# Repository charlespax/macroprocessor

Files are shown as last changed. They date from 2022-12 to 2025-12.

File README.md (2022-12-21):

# macroprocessor
A project to create a microprocessor optimized for human visual verification

# Introduction
A user should be able to trust the output of a computational device without having to trust
the computatoinal device itself.

# Application
## Cryptographic security
Bitcoin

# Design
The design is not optimized for price, area, power, efficiency, yield, or other 
traditional parameter. The design is optimized for human readability and understanding.

## Requirements
- MUST be visible to a human with minimal optical magnification
- An integrated circuit design layout SHOULD aid understanding
- IC layout SHOULD correspond to the layout as seen in a digitial simulation
- Microprocessor design architecture SHOULD be optimized for understanding
- The registers or other circuitry MAY emit light
- MAY have features to aid cryptography
- MAY have serial output for debugging or other purposes

## Design notes
The overall chip layout and data flow SHOULD run from left to right.

Logical elements SHOULD have inputs on the left and outputs on the right

The metal layer or other features MUST NOT obscure any features such that 
the circuit can not be verified visually.

Chip packaging MUST NOT obscure the electrical path from the IC to the
package pins.

The design MAY use multiple IC components if each component meets the
requirements of this document.

The design MAY include wire-bonded components

# Notes
- RISC-V RV32I or RV32E are candidates
- Research making a Forth-native processor
- Can the macroprocessor be made using the same process as LEDs?
- Can a wafer be put through a secondary LED process to create registers that
  emit light?
- What is the current state of light-emitting transistors (LETs)?
- Can I use diode logic and use LEDs?
- I believe the normal silicon process cannot be used to create features that
  emit light because the band gap of silicon is too greaet. True?
- RISC-V would be a great choice if it can be visually verified. This has the 
  advantage that many more eyes would be on the chip. However, I think it is
  more important to make choices that result in more users in verifying their
  own devices.
- Check out https://zeroToASICCourse.com - this is a course for designing and ordering
  your own chip designs.
- Check out https://developers.google.com/silicon - Google's wafer batching
  program for open source designs. Cool, but I am happy to pay if reasonable.
- MAY take an external diode-based ROM
- Is there anything about this processor that would make it bad at cryptographic
  functions? Minimal circuitry could be included to address issues.
- Can x-ray crystalography be used to verify the surface of an IC?
- https://www.skywatertechnology.com is a US-based silicon fab. 
- What happens to the equipment from old semiconductor fabrication technologies?
- Fab technologies: https://en.wikipedia.org/wiki/Semiconductor\_device\_fabrication
- Are there fabs that use old technologies for new chips?
- Wire bonding can be used in places where the metal layer would obscure layers below
- wire bonding can be used as jumpers that can be cut to permanently disable a ffeature
- Rather than wire bonding, the connections can be routed to the outside of the package,
  so they can be explicetly enabled
- Maybe multi gate transistors can be used on such large features if one large gate is
  not appropriate
- Make the binary instruction decoding physicallyl easy to see on the die. Put them
  in the same order you would find them in a specification table
- Is silicon transparent to any frequency of light? If so, maybe  this can be
  used for verification and would be a design consideration.

# Conventions
The keywords below are to be interpreted as described in BCP14 [RFC2119] [RFC8174].
- MUST
- MUST NOT
- REQUIRED
- SHOULD
- SHOULD NOT
- RECOMMENDED
- NOT RECOMMENDED
- MAY
- OPTIONAL

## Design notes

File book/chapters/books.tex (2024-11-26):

\setchapterimage{seaside}
\setchapterpreamble[u]{\margintoc}
\chapter{Books}
\labch{Books}

This chapter is just a bunch of books.

Starting FORTH by Leo Brodie \cite{Brodie1981}

Thinking Forth by Leo Brodie \cite{Brodie1984}

Stack Computers: The New Wave by Philip J. Koopman \cite{Koopman1989}

Threaded Interpretive Languages by R. G. Loeliger \cite{Loeliger1981}

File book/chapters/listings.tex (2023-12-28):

\setchapterimage{seaside}
\setchapterpreamble[u]{\margintoc}
\chapter{Code Listings}
\labch{codelistingsn}

\fixed{\textbf{!}}\hspace{2mm} ( $n$ \ $addr$ --- ) Store $n$ at $addr$.
\begin{lstlisting}
    : !  ( n addr -- )
        TOS> ,>MAR
        TOS> ,>PM
\end{lstlisting}

\fixed{\textbf{:}}\hspace{2mm} ( --- ) Colon definition. Create a new word.
Usage:  : <word> <...> ;
\begin{lstlisting}
    : :  ( -- )
\end{lstlisting}

\fixed{\textbf{;}}\hspace{2mm} ( --- ) Terminate a colon definition. Resume interpretation.
Usage: : <word> <...> ;
\begin{lstlisting}
    : ;  ( -- )
\end{lstlisting}

\fixed{\textbf{>r}}\hspace{2mm} ( n --- ) Move $n$ from data stack to return stack.
\begin{lstlisting}
    : >r  ( n -- )
        TOS> ,>RS
\end{lstlisting}

\fixed{\textbf{@}}\hspace{2mm} ( $addr$ --- $n$ ) Put on TOS the value $n$ stored at address $addr$.
\begin{lstlisting}
    : @  ( addr -- n )
        TOS> ,>MAR
        PM> ,>TOS
\end{lstlisting}

\fixed{\textbf{(create)}} 
\begin{lstlisting}
    : (create)  ( -- )
\end{lstlisting}

\fixed{\textbf{,}}\hspace{2mm} Allot one cell of dictionary space. Store n at that cell's address.
\begin{lstlisting}
    : ,  (n -- ) 
                 
\end{lstlisting}

\fixed{\textbf{blk}}\hspace{2mm} User variable. Located at address \fixed{addr} is the number
of the block being interpreted.
\begin{lstlisting}
    : blk  ( -- addr ) ( User variable. Located at address addr )
                       ( is the number )
                       ( of the block being interpreted )
\end{lstlisting}

\fixed{\textbf{here}}
\begin{lstlisting}
    : here  ( -- addr ) ( Put on TOS the address of the next free )
                        ( cell in the dictionary )
\end{lstlisting}

\fixed{\textbf{interpret}}\hspace{2mm} ( --- ) Interpret the input string.
\begin{lstlisting}
    : interpret  ( -- )
\end{lstlisting}

\fixed{\textbf{next}}\hspace{2mm} ( --- ) Compile the machine instructions which simulate the 
Forth machine's \fixed{next} function. Must be used at the exit point of each code or ;code
definition.
\begin{lstlisting}
    : next  ( -- )
\end{lstlisting}

\fixed{\textbf{r>}}\hspace{2mm} ( --- $n$ ) Move $n$ from return stack to data stack.
\begin{lstlisting}
    : r>  ( ( -- n )
        RS> ,>TOS
\end{lstlisting}

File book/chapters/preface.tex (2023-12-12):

\chapter*{Preface}
\addcontentsline{toc}{chapter}{Preface} % Add the preface to the table of contents as a chapter

This is the preface page. This book is broken into two parts:

\begin{itemize}
	\item Hardware
	\item Software
\end{itemize}

The main goal of this project is to create a system that a user can visually verify down
to the transistor level. The physical layout of the circuit should correspond to the
schematic drawing layout where possible.

\begin{flushright}
	\textit{Charles Edward Pax}
\end{flushright}

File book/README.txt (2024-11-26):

Kaobook
-------------------
This book uses the kaobook templates found at
https://github.com/fmarotta/kaobook

Kaobook files:
    kaobook.cls
    kaohandt.cls
    kao.sty
    kaobiblio.sty
    kaorefs.sty
    kaotheorems.sty

My main document file is main.tex

To compile the main kaobook sample document, execute compileall.sh.

To remove generated files, execute clean.sh.

Commands to get setup the compile environment in Linux Mint 21.2:
sudo apt-get install texlive texlive-latex-extra texlive-fonts-extra texlive-science texlive-bibtex-extra biber xindy

You sould probably accomplish the same thing by installing texlive-full, but
I have not tried this.
sudo apt-get install texlive-full

Troubleshooting
-------------------

Error: `biblatex.sty' not found
Solution:  sudo apt-get install texlive-bibtex-extra biber

Glossary not compiling
sudo apt-get install xindy

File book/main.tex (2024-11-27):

%----------------------------------------------------------------------------------------
%	PACKAGES AND OTHER DOCUMENT CONFIGURATIONS
%----------------------------------------------------------------------------------------

\documentclass[
    letterpaper, % Page size: letterpaper (8.5x11 in, a4paper, executivepaper (7x10 in)
	fontsize=10pt, % Base font size
	twoside=true, % Use different layouts for even and odd pages 
                      % (in particular, if twoside=true, the margin column will be always on the outside)
	%open=any, % If twoside=true, uncomment this to force new chapters to start on any page, not only on right (odd) pages
	%chapterentrydots=true, % Uncomment to output dots from the chapter name to the page number in the table of contents
	numbers=noenddot, % Comment to output dots after chapter numbers; the most common values for this 
                          % option are: enddot, noenddot and auto (see the KOMAScript documentation for an in-depth explanation)
]{kaobook}

% Choose the language
\ifxetexorluatex
	\usepackage{polyglossia}
	\setmainlanguage{english}
\else
	\usepackage[english]{babel} % Load characters and hyphenation
\fi
\usepackage[english=british]{csquotes}	% English quotes

% Load packages for testing
\usepackage{blindtext} % Similar to lorem ipsum
%\usepackage{showframe} % Uncomment to show boxes around the text area, margin, header and footer
%\usepackage{showlabels} % Uncomment to output the content of \label commands to the document where they are used

% Load the bibliography package
\usepackage{kaobiblio}
\addbibresource{main.bib} % Bibliography file

% Load mathematical packages for theorems and related environments
\usepackage[framed=true]{kaotheorems}

% Load the package for hyperreferences
\usepackage{kaorefs}

\graphicspath{{examples/documentation/images/}{images/}} % Paths in which to look for images

\makeindex[columns=3, title=Alphabetical Index, intoc] % Make LaTeX produce the files required to compile the index

\makeglossaries % Make LaTeX produce the files required to compile the glossary
\input{glossary.tex} % Include the glossary definitions

\makenomenclature % Make LaTeX produce the files required to compile the nomenclature

% Reset sidenote counter at chapters
%\counterwithin*{sidenote}{chapter}

% Load the package for byte field graphic generation
% https://ctan.org/pkg/bytefield
\usepackage{bytefield}

% Load the package for timing diagrams
% https://ctan.org/pkg/tikz-timing
\usepackage{tikz-timing}[2009/05/15]

% Load package for drawing diagrams
\usetikzlibrary{positioning, matrix, arrows.meta,calc}

% New Command for fixed width text
\newcommand{\fixed}[1]{\texttt{#1}}

%----------------------------------------------------------------------------------------
% Packages to consider
%----------------------------------------------------------------------------------------
% CircuiTikZ
% https://ctan.org/pkg/circuitikz
% The package provides a set of macros for naturally typesetting electrical and (somewhat 
% less naturally, perhaps) electronic networks. 

%----------------------------------------------------------------------------------------
% Notes
%----------------------------------------------------------------------------------------
% - This Reddit thread has many good links for understanding the inner workings of
%   the Forth system.
%   https://www.reddit.com/r/Forth/comments/8j6rsw/i_dont_understand_whats_happening_under_the_hood/
%
% - Check out preForth and seedForth. There's a video on youtube
%
% - Structure the book based on abstraction layers
%   * Instruction Set Architecture
%   * Machine Architecture
%   * Machine code
%   * Hardware Architecture
%   * Hardware virtualization
%   * ASIC implementation

%---------------------------------------------------------------------------------------

\begin{document}

%----------------------------------------------------------------------------------------
%	BOOK INFORMATION
%----------------------------------------------------------------------------------------

%\titlehead{The \texttt{kaobook} class}
%\subject{Use this document as a template}

\title[The Forth Enlightenment]{The Forth Enlightenment}
\subtitle{Hardware for the Forth programming language}

\author[Charles Edward Pax]{Charles Edward Pax}

\date{\today}

\publishers{Self-publishing}

%----------------------------------------------------------------------------------------

\frontmatter % Denotes the start of the pre-document content, uses roman numerals

%----------------------------------------------------------------------------------------
%	OPENING PAGE
%----------------------------------------------------------------------------------------

%\makeatletter
%\extratitle{
%	% In the title page, the title is vspaced by 9.5\baselineskip
%	\vspace*{9\baselineskip}
%	\vspace*{\parskip}
%	\begin{center}
%		% In the title page, \huge is set after the komafont for title
%		\usekomafont{title}\huge\@title
%	\end{center}
%}
%\makeatother

%----------------------------------------------------------------------------------------
%	COPYRIGHT PAGE
%----------------------------------------------------------------------------------------

%\makeatletter
%\uppertitleback{\@titlehead} % Header
%
%\lowertitleback{
%	\textbf{Disclaimer}\\
%	Warranty disclaimer here
%	
%	\medskip
%	
%	\textbf{Copyright}\\
%	Copyright \textcopyright 2023 Charles Edward Pax. All rights reserved, for now.
%	
%	\medskip
%	
%	\textbf{Colophon} \\
%	This document was typeset with the help of \href{https://sourceforge.net/projects/koma-script/}{\KOMAScript} 
%       and \href{https://www.latex-project.org/}{\LaTeX} using the \href{https://github.com/fmarotta/kaobook/}{kaobook} class.
%	
%	The source code of this book template is available at:\\\url{https://github.com/fmarotta/kaobook}
%	
%	\medskip
%	
%	\textbf{Publisher} \\
%	First printed in December 2023 by \@publishers
%}
%\makeatother

%----------------------------------------------------------------------------------------
%	DEDICATION
%----------------------------------------------------------------------------------------

%\dedication{
%	It would be nice to have a dedication to a person or group of people.\\
%	\flushright -- Charles Edward Pax
%}

%----------------------------------------------------------------------------------------
%	OUTPUT TITLE PAGE AND PREVIOUS
%----------------------------------------------------------------------------------------

% Note that \maketitle outputs the pages before here

\maketitle

%----------------------------------------------------------------------------------------
%	PREFACE
%----------------------------------------------------------------------------------------

%\input{chapters/preface.tex}
%\index{preface}

%----------------------------------------------------------------------------------------
%	TABLE OF CONTENTS & LIST OF FIGURES/TABLES
%----------------------------------------------------------------------------------------

\begingroup % Local scope for the following commands

% Define the style for the TOC, LOF, and LOT
%\setstretch{1} % Uncomment to modify line spacing in the ToC
%\hypersetup{linkcolor=blue} % Uncomment to set the colour of links in the ToC
\setlength{\textheight}{230\hscale} % Manually adjust the height of the ToC pages

% Turn on compatibility mode for the etoc package
\etocstandarddisplaystyle % "toc display" as if etoc was not loaded
\etocstandardlines % "toc lines" as if etoc was not loaded

\tableofcontents % Output the table of contents

%\listoffigures % Output the list of figures

% Comment both of the following lines to have the LOF and the LOT on different pages
\let\cleardoublepage\bigskip
\let\clearpage\bigskip

%\listoftables % Output the list of tables

\endgroup

%%%==============================================================================%%%
%%%==============================================================================%%%
%%%                                                                              %%%
%%%    ███╗   ███╗ █████╗ ██╗███╗   ██╗    ██████╗  ██████╗ ██████╗ ██╗   ██╗    %%%
%%%    ████╗ ████║██╔══██╗██║████╗  ██║    ██╔══██╗██╔═══██╗██╔══██╗╚██╗ ██╔╝    %%%
%%%    ██╔████╔██║███████║██║██╔██╗ ██║    ██████╔╝██║   ██║██║  ██║ ╚████╔╝     %%%
%%%    ██║╚██╔╝██║██╔══██║██║██║╚██╗██║    ██╔══██╗██║   ██║██║  ██║  ╚██╔╝      %%%
%%%    ██║ ╚═╝ ██║██║  ██║██║██║ ╚████║    ██████╔╝╚██████╔╝██████╔╝   ██║       %%%
%%%    ╚═╝     ╚═╝╚═╝  ╚═╝╚═╝╚═╝  ╚═══╝    ╚═════╝  ╚═════╝ ╚═════╝    ╚═╝       %%%
%%%                                                                              %%%
%%%  https://patorjk.com/software/taag/#p=display&f=ANSI%20Shadow&t=MAIN%20BODY  %%%
%%%==============================================================================%%%
%%%==============================================================================%%%

\mainmatter % Denotes the start of the main document content, resets page numbering and uses arabic numbers
\setchapterstyle{kao} % Choose the default chapter heading style

\input{chapters/introduction.tex}
\input{chapters/hardware.tex}
\input{chapters/instructionsetarchitecture.tex}
\input{chapters/forth.tex}
\input{chapters/system.tex}
\input{chapters/chaptertemplate.tex}
\input{chapters/listings.tex}

\appendix % From here onwards, chapters are numbered with letters, as is the appendix convention

\input{chapters/appendix.tex}

%----------------------------------------------------------------------------------------

\backmatter % Denotes the end of the main document content
\setchapterstyle{plain} % Output plain chapters from this point onwards

%----------------------------------------------------------------------------------------
%	BIBLIOGRAPHY
%----------------------------------------------------------------------------------------

% The bibliography needs to be compiled with biber using your LaTeX editor, or on the command line with 'biber main' from the template directory

\defbibnote{bibnote}{Works are listed in order of first citation.\par\bigskip} % Prepend this text to the bibliography
\printbibliography[heading=bibintoc, title=Bibliography, prenote=bibnote] % Add the bibliography heading to the ToC, set the title of the bibliography and output the bibliography note

Title:  Implementing the Forth Inner Interpreter in High Level Forth
Date:  2016-09
URL:  http://www.euroforth.org/ef16/papers/hoffmann.pdf
Abstract:  This document defines a Forth threaded code (inner) interpreter written entirely in
    high level standard Forth. For this it defines a specific threaded code structure of colon
    definitions, a compiler from high level Forth to this threaded code and a corresponding
    inner interpreter to execute it. This inner interpreter can run in a stepwise way and so gives
    the surrounding environment control of its execution behavior. A real time environment
    thus might slice the execution of threaded code in small pieces and provide an interactive
    command shell while still meeting its real time requirements.
References:
    [1] A synchronous FORTH framework for hard real-time control, U. Hoffmann and A. Read, euroForth 2016
    [2] Threaded Interpretive Languages: Their Design and Implementation, R. G. Loeliger, McGraw Hill, 1981
Notes:
   - This paper describes a Forth inner interpreter that runs inside a Forth system. This allows
   the Forth system to control the execution of the 'virtual' interpreter. This is relevant
   to Real-Time Operating Systems (RTOS).
   - This paper is not relevant to the MacroProcessor Forth system

Title:  Fig-Forth internals
Date: 2021-09
URL:  https://www.jimbrooks.org/archive/programming/forth/FIG-FORTH\_internals.php
Abstract:  My notes from studying and modifying 8086 assembly code of FIG-FORTH. Describes
    how FIG-FORTH interpreter executes internally, how interpreting and compiling are virtually 
    the same operation, ingenious solutions used to assemble FORTH interpreter. Also describes 
    modifying FIG-FORTH to have direct-threaded code (DTC). 
Notes:
    - These notes are likely to be useful in understanding more low-level information.
    - This is not a walkthrough of the Forth system
    -"When FORTH starts, it begins executing machine-code of physical CPU. FORTH registers 
    IP SP RP of FORTH virtual processor are initialized. System words COLD WARM ABORT are 
    executed which completes initialization. ABORT executes QUIT"
    - "During execution of COLD which starts a FIG-FORTH system, QUIT creates command 
    prompt. QUIT contains words QUERY INTERPRET. QUERY accepts commands, INTERPRET 
    interprets or compiles them. QUIT emits OK message after INTERPRET returns."

%----------------------------------------------------------------------------------------
%	NOMENCLATURE
%----------------------------------------------------------------------------------------

% The nomenclature needs to be compiled on the command line with 'makeindex main.nlo -s nomencl.ist -o main.nls' from the template directory

\nomenclature{$c$}{Speed of light in a vacuum inertial frame}
\nomenclature{$h$}{Planck constant}
\nomenclature{CFA}{See Code Field Address}
\nomenclature{LFA}{See Link Field Address}
\nomenclature{NFA}{See Name Field Address}
\nomenclature{PFA}{See Parameter Field Address}

\renewcommand{\nomname}{Notation} % Rename the default 'Nomenclature'
\renewcommand{\nompreamble}{The next list describes several symbols that will be later used within the body of the document.} % Prepend this text to the nomenclature

\printnomenclature % Output the nomenclature

%----------------------------------------------------------------------------------------
%	GLOSSARY
%----------------------------------------------------------------------------------------

% The glossary needs to be compiled on the command line with 'makeglossaries main' from the template directory

\setglossarystyle{altlist} % Set the style of the glossary (see https://en.wikibooks.org/wiki/LaTeX/Glossary for a reference)
\glsaddall % print all terms in the glossary, not only referenced words
\printglossary[title=Glossary, toctitle=Glossary,nonumberlist] % Output the glossary, 'title' is the chapter heading for the glossary, toctitle is the table of contents heading

Dictionary
===================

;  "Semi-colon"
Terminates a definition created by : .

1. Exits colon definition mode
2. Addes the definition to the dictionary
3. Enters interpretation mode

    : ; ( -- )
        ( definition goes here ) ;

NEXT  "Next"
Terminates a code-word and jumps to the next instruction.

1. Fetch the Code Field Address (CFA),
   which is stored in a cell,
   which is pointed to by the Forth Instruction Pointer (IP)
2. Increment the Forth IP,
   which will then point to the proceeding cell,
   which contains the next Forth instruction
3. Jump to the fetched CFA

    : NEXT ( -- )
        RS> ,>PC ,R--

Notes:
   - What is a cell? I think this is address of the code field of the
   proceeding Forth word. The IP always points to the next CFA to be
   executed.
   - Does the cell located at the CFA hold a machine instruction or
   is there a Forth dictionary word there? I think the contents of the
   cell pointed to by the CFA in the IP is always a machine instruction.
   I think the word INTERPRET handles the task of looking through the
   dictionary and determining the CFA of that word. The CFA should be
   the first cell of a word's code field, which can be one or more cells.

%----------------------------------------------------------------------------------------
%	INDEX
%----------------------------------------------------------------------------------------

% The index needs to be compiled on the command line with 'makeindex main' from the template directory

\printindex % Output the index

%----------------------------------------------------------------------------------------
%	BACK COVER
%----------------------------------------------------------------------------------------

% If you have a PDF/image file that you want to use as a back cover, uncomment the following lines

%\clearpage
%\thispagestyle{empty}
%\null%
%\clearpage
%\includepdf{cover-back.pdf}

%----------------------------------------------------------------------------------------

\end{document}

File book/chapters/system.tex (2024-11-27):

\setchapterimage{seaside}
\setchapterpreamble[u]{\margintoc}
\chapter{The Forth System}
\labch{chaptertemplate}

%
% Key concepts and abilities
%==============================================================================
\begin{kaobox}[frametitle=In This Chapter]
you will learn
\begin{itemize}
	\item what is the first topic
	\item how to identify the second topic
        \item best practices for the third topic
\end{itemize}

you will be able to
\begin{itemize}
        \item perform the steps required to accomplish task one
        \item create a program that performs task two
\end{itemize}
\end{kaobox}

This introduction gives the reader any context necessary to understand the 
proceeding sections in this chapter.

The contents of the `In This Chapter' box should concrete. This should coorespond to
a `Chapter Review' section at the end of the chapter.

Illuminate any common obstacles for the reader. A few words of encouragement are also welcomed.

%
% Section: Things Forth Does
%==============================================================================
\section{Things Forth Does}
\subsection{System Operations}
Note: the text interpreter handles input from terminal and files. It also 
handles compilation

\subsubsection{Initialize system}
Copy values into the correct location in memory. Set register values. Example: 
Read from memory the designated address for the stack pointer and load that 
into a particular register.

\subsubsection{Interpret input stream}
The outer interpreter (AKA text interpreter). The input stream could be a 
keyboard buffer, serial buffer, or other source.

\subsubsection{Execution}
'Innter interpreter.' 'Address interpreter.' Track which word is being executed
and which to execute next. Jumping to machine code. Controls the flow of 
execution.

\subsubsection{Error detection and handling}
Usually by clearing the stack and returning control to the outer interpreter.

%
% Section: Forth System Parameters
%==============================================================================
\section{Forth System Parameters}
Data Stack Pointer (DS), Return Stack Pointer (RS), Interpreter Pointer(IP),
Word Pointer (W).

Data Stack Pointer. Holds the address of the top cell of the data stack. SP can be in memory or in a register. Register is better. This paragraph is true for systems that have the stack in RAM.

The data stack can be held in memory or in hardware stack provided by the CPU. The same is true of the return stack.

When using a hardware stack provided by the CPU, the Top of Stack (ToS) element is typically the only element that can be accessed by the data bus. Some microprocessors provide access to multiple cells. Three cells are a good number (Stack Computers?).

Return Stack Pointer (RS). Similar to the data stack. The data stack pointer and the data stack itself can beach be stored in memory. RS can be a hardware stack, but doing so does not provide the same performence gain as doind so with the data stack (source?).

During execution, a word may use the Return Stack for temkporary storage. Be careful!

Interpretative Pointer (IP). 'instruction pointer?'. Points to the code field (?) of the next word to be executed. Does thi depend on the system implementation? Can be stored in memory or a register.

Word Pointer (WP). Points to the word currently being executed. (Name field? Code field?).
% Chapter Review
%==============================================================================
\section{Chapter Review}
\begin{kaobox}[frametitle=Chapter Review]
you have learned
\begin{itemize}
	\item what is the first topic
	\item how to identify the second topic
        \item best practices for the third topic
\end{itemize}

you are able to
\begin{itemize}
        \item perform the steps required to accomplish task one
        \item create a program that performs task two
\end{itemize}
\end{kaobox}

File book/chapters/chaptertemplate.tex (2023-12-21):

\setchapterimage{seaside}
\setchapterpreamble[u]{\margintoc}
\chapter{Template Chapter}
\labch{chaptertemplate}

%
% Key concepts and abilities
%==============================================================================
\begin{kaobox}[frametitle=In This Chapter]
you will learn
\begin{itemize}
	\item what is the first topic
	\item how to identify the second topic
        \item best practices for the third topic
\end{itemize}

you will be able to
\begin{itemize}
        \item perform the steps required to accomplish task one
        \item create a program that performs task two
\end{itemize}
\end{kaobox}

This introduction gives the reader any context necessary to understand the 
proceeding sections in this chapter.

The contents of the `In This Chapter' box should concrete. This should coorespond to
a `Chapter Review' section at the end of the chapter.

Illuminate any common obstacles for the reader. A few words of encouragement are also welcomed.

%
% Section: Heaps of Examples
%==============================================================================
\section{Heaps of Examples}
This section is fairly dense with examples. You can delete everything from here until
the end of the page.\sidenote[]{After you have saved this document as a new file.}

This section serves as an easy way to demonstrate\footnote{Like this footnote} multiple 
graphical elements\todo{Add a list of elements} that can be used in this book.

Keep chapters, sections, and sub sections capitalized.

%
% Subsection: Margin Stuff
%------------------------------------------------------------------------------
\subsection{Margin Stuff}
Generally, any text that would be written between parentheses would do well as
a margin note. Keep the flow going.

\marginnote{
	\begin{kaobox}[frametitle=Remember]
		a kaobox can be used in the margins for special reminders)
	\end{kaobox}
}

%
% Subsubsection: Sections in Depth
%
\subsubsection{Sections in Depth}
Sections within a chapter can be \Command{section}, \Command{subsection}, or
\Command{subsubsection}\marginnote{Notice that \Command{subsubsection} does not cause numbering.}.

%
% Subsection: Figures and Tables}
%------------------------------------------------------------------------------
\subsection{Figures and Tables}
\begin{lstlisting}[caption={
This Forth code does NOT generate \reftab{useless}
}]
: square  ( x -- x )
( Forth code that squares a number
    dup * ;
\end{lstlisting}

This is an example of a table contained withing the main column of text.

\begin{table}[ht]
\caption[A useless table]{A useless table.}
\labtab{useless}
\begin{tabular}{ c c c c }
    \toprule
    col1          & col2  & col3  & col4\\
    \midrule
    \multirow{3}{4em}{
    Multiple row} & 
        cell2 & cell3 & cell4\\ &
        cell5 & cell6 & cell7 \\ &
        cell8 & cell9 & cell10 \\
    \multirow{3}{4em}{
    Multiple row} & 
        cell2 & cell3 & cell4 \\ &
        cell5 & cell6 & cell7 \\ &
        cell8 & cell9 & cell10 \\
    \bottomrule
\end{tabular}
\end{table}

We can also have full-width tables.

\begin{table*}[h!]
    \caption{A wide table with invented data about three people living in the UK. Note that wide figures and tables are centered and their caption also extends into the margin.}
    \begin{tabular}{p{2.0cm} p{2.0cm} p{2.0cm} p{2.0cm} p{2.0cm} p{2.0cm} p{1.5cm}}
        \toprule
        Name    & Surname   & Job       & Salary           & Age   & Height    & Country \\
        \midrule
        Alice   & Red       & Writer    & 4.000 \pounds    & 34    & 167 cm     & England \\
        Bob     & White     & Bartender & 2.000 \pounds    & 24    & 180 cm     & Scotland \\
        Drake   & Green     & Scientist & 4.000 \pounds    & 26    & 175 cm     & Wales \\
        \bottomrule
    \end{tabular}
\end{table*}

And full-width images.

\blindtext

\begin{figure*}[h!]
	
	\caption[A wide seaside]{A wide seaside, and a wide caption.
		Credits: By Bushra Feroz, CC BY-SA 4.0, \url{https://commons.wikimedia.org/w/index.php?curid=68724647}}
\end{figure*}

\begin{marginfigure}
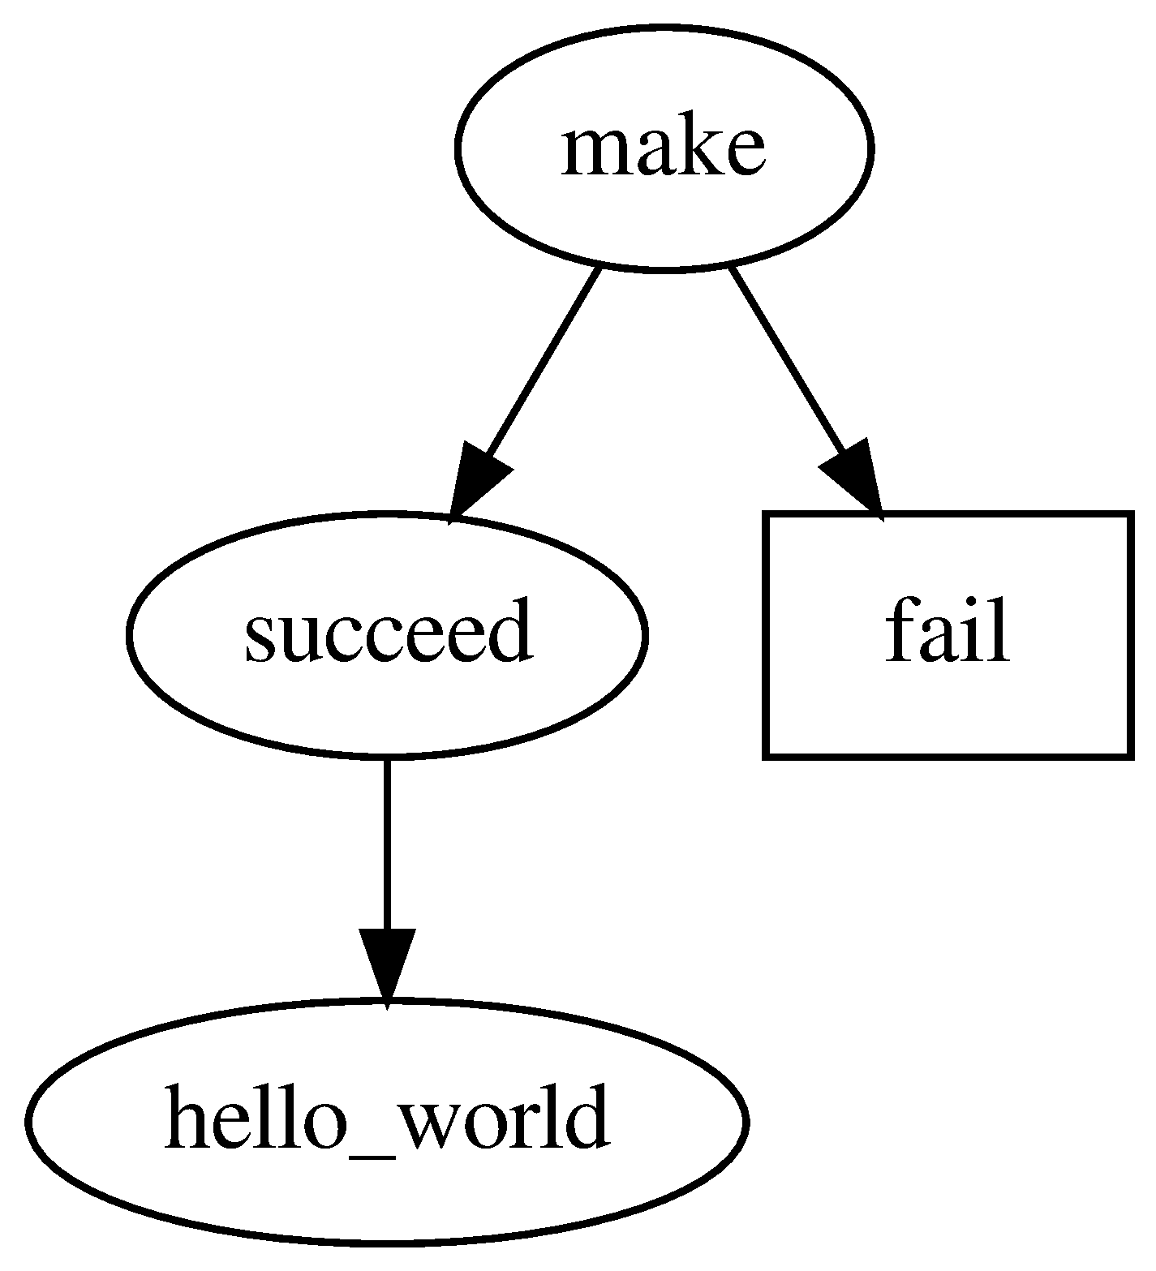
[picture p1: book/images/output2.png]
	
	\caption[A Dot diagram]{A diagram produced by the Dot program and saved as a PNG file.}
	\labfig{marginmonalisa}
\end{marginfigure}

%
% Subsection: Citations
%------------------------------------------------------------------------------
\subsection{Citations}
Cite an author in the margin\sidecite{example1999}.

\blindtext

%
% Subsection: Glossaries and Indicies
%------------------------------------------------------------------------------
\subsection{Glossaries and Indicies}

%
% Subsection: Mathematics
%------------------------------------------------------------------------------
\subsection{Mathematics}
The box below was created using the \Environment{definition} environment. Boxes are also
provided by the \Environment{theorem}, \Environment{proposition}, \Environment{lemma},
\Environment{corollary}, \Environment{example}, \Environment{remark}, and \Environment{exercise} environments.

\begin{definition}
\labdef{exdeflabel}
Let $y$ be some function of $x$ such that $y = f(x)$
\end{definition}

where $x$ and $y$ are both variables in \refdef{exdeflabel}.

\blindtext

%
% Chapter Review
%==============================================================================
\section{Chapter Review}
\begin{kaobox}[frametitle=Chapter Review]
you have learned
\begin{itemize}
	\item what is the first topic
	\item how to identify the second topic
        \item best practices for the third topic
\end{itemize}

you are able to
\begin{itemize}
        \item perform the steps required to accomplish task one
        \item create a program that performs task two
\end{itemize}
\end{kaobox}

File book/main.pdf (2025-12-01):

# The Forth Enlightenment

Hardware for the Forth programming language

## Charles Edward Pax

## December 11, 2024

## Self-publishing

# Contents

Contents | iii
1 Introduction | 1
2 Hardware | 3
3 Instruction Set Architecture (ISA) | 7
4 The Forth Programming Language | 11
5 The Forth System | 17
6 Template Chapter | 21
7 Code Listings | 25
A Template Appendix | 27
Bibliography | 29

Notation | 31
Glossary | 33
Alphabetical Index | 35

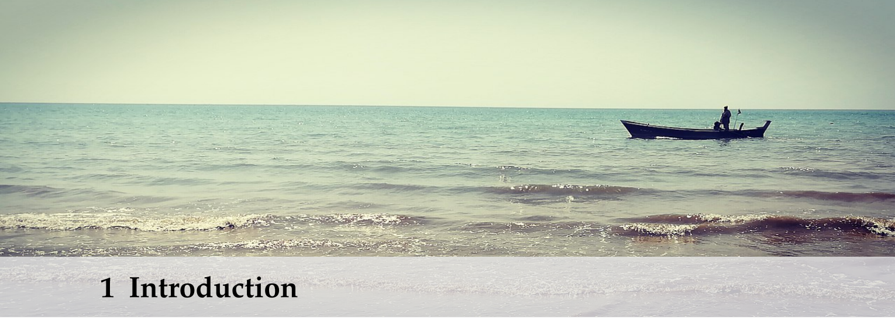
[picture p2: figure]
1 Introduction

### 1.3 Instruction set Architecture . 2

In This Chapter

you will learn

- First topic
- Second topic
- Third topic

you will be able to

- Task one
- Task two
- Task three

Hello, here is some text without a meaning. This text should show what a printed text will look like at this place. If you read this text, you will get no information. Really? Is there no information? Is there a difference between this text and some nonsense like “Huardest gefburn”? Kjift – not at all! A blind text like this gives you information about the selected font, how the letters are written and an impression of the look. This text should contain all letters of the alphabet and it should be written in of the original language. There is no need for special content, but the length of words should match the language.

## 1.1 Purpose

The purpose of this book is to address the necessity of trustless computing or verifyable computing.

- Don’t trust, verify
- trustless computing
- trusting the compiler

Design princples: simplicity is a virtue.

2 1 Introduction

### Don’t trust, verify

In this section talk about blah blah blah.

### Trustless computing

Discuss trustless computing here.

### Trusting the compilers

In this subsection there will be a discussion of trusting the compiler.

### Application: Bitcoin

These topics are relevant to Bitcoin because it relates to money. Don’t get hacket. Artificial Intelligence is coming for your money.

## 1.2 Hardware Overview

No microcode. Implement logic in hardware. Complex optimization is bad. conceptual simplicity. Simplicity is a cirtue.

visual verification view with your own eyes
simplicity keep it simple to understand
repitation repeat blocks

### Stack computers

- Why stack computers?
- Parts of a stack computer
- Types of stack computers

Do we cover the instruction cycle here? Instruction timing?

## 1.3 Instruction set Architecture

The instruction set architecture should be kept simple. Each bit encodes specific information.

The software should:

- be simple
- reuse code blocks
- not require a compiler
- be hand-writable

Threaded code. No compiler. Forth.

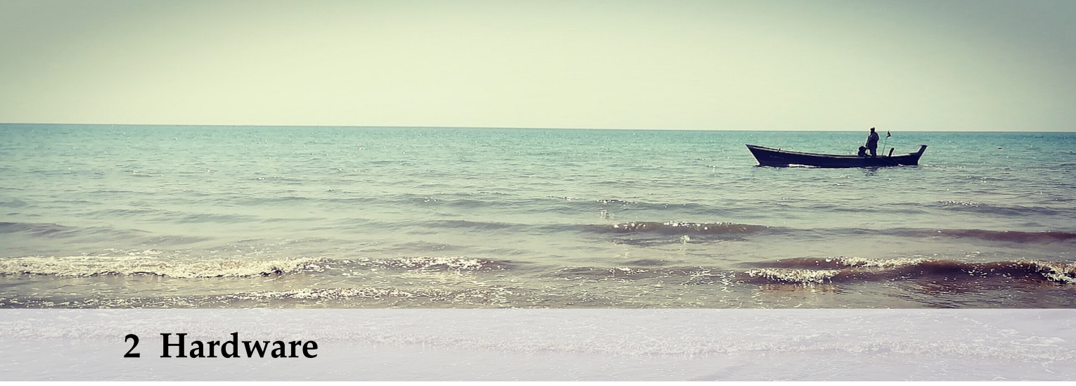
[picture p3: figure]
2 Hardware

[1]: Philip J. Koopman (1989), Stack Computers the New Wave

### 2.2 Architecture Block Diagram 3

In This Chapter

you will learn

- First topic
- Second topic
- Third topic

you will be able to

- Task one
- Task two
- Task three

Hello, here is some text without a meaning. This text should show what a printed text will look like at this place. If you read this text, you will get no information. Really? Is there no information? Is there a difference between this text and some nonsense like “Huardest gefburn”? Kjift – not at all! A blind text like this gives you information about the selected font, how the letters are written and an impression of the look. This text should contain all letters of the alphabet and it should be written in of the original language. There is no need for special content, but the length of words should match the language.

## 2.1 Stack Computers

We will discuss stack computers[1].

## 2.2 Architecture Block Diagram

4 | 2 Hardware
1 | \ | +-----+ | |||====\\ | //=====\\
2 | \ | | PC | |<===>||| | || | || | ||
3 | \ | +-----+ | | | __\/_ _\/__ | ||
4 | \ | |D| \ A | \/ | B / | ||
5 | \ | +-----+ | +-----+ | |A| | \ | ALU | / | ||
6 | \ | | IO | |==| MAR |<====|T| | \______/ | ||
7 | \ | +-----+ | +-----+ | |A| | | || | | ||
8 | \ | || | | | | +------+ | ||
9 | \ | +-----+ | |B|<====| TOS | |====//
10 | \ | | PM | |<===>|U| | +------+
11 | \ | +-----+ | |S|<===>| DS1 | |
12 | \ | | | | +------+
13 | \ | +-----+ | |||<===>| DS2 | |
14 | \ | | IR | |<===>||| | +------+
15 | \ | +-----+ | ||| | +------+
16 | \ | | CL | | | ||| | | DS31 |
17 | \ | +-----+ | ||| | +------+
18 | \ | | | |||
19 | \ | ||| | +------+
20 | \ | |||<====| RS | |
21 | \ | ||| | +------+
22 | \ | ||| | +------+
23 | \ | | RS31 |
24 | \ | +------+

Figure 2.1: Simplified architecture block diagram

2.2 Architecture Block Diagram | 5
1 | |||======================\\ | //====\\
2 | ||| | || | || | ||
3 | ||| 000 ALU_NOP | || | || | ||
4 | ||| 001 ALU_ADD | || | || | ||
5 | ||| 010 ALU_SUB | __\/___ ___\/__ ||
6 | | | 011 ALU_AND | \ | A | \/ | B | / | ||
7 | | | 100 ALU_OR | \ | / | ||
8 | +-------------------+ | 001 PC> | |1| 101 ALU_XOR | \ | ALU | / | ||
9 | | | Program | | | | |6| 110 ALU_<< | ALU_OP --\________/ | ||
10 | | | Counter | |=============#=>| | 111 ALU_>> | || | ||
11 | | | |<===============|B| | || | ||
12 | SMA_x --| (1 PC++) | |-- 001 >PC | |I| 101 TOS> | +----------\/----+ | ||
13 | | | | | |T| | | | | Top Of | | | ||
14 | +-------------------+ | | |<=#=============| | Stack | |====//
15 | || | |D| | | | |
16 | || | |A| | 101 >TOS --| | (cell 0) | |
17 | +---\/----+---------+ | 010 PM> | |T| 110 DS1> | +----------------+
18 | | Memory | | Program | | | |A| | | | | Data | |
19 | | Address | Memory |=============#=>| |<=#=============| | Stack | |
20 | | | | | |<===============|B|===============>| | Cell 1 | |
21 | SMA_x --| | | | |-- 010 >PM | |U| | 110 >DS1 --| | |
22 | 0 MAR +---/\----+---------+ | |S| 111 DS2> | +----------------+
23 | 1 PC | || | | | | | | | Data | |
24 | || | | |<=#=============| | Stack | |
25 | +-------------------+ | |||===============>| | Cell 2 | |
26 | | Memory | |<===============||| | 111 >DS2 --| | |
27 | | Address Register |-- 011 >MAR | ||| | +----------------+
28 | +-------------------+ | ||| | . | .
29 | ||| | +----------------+
30 | +-------------------+ | ||| | | | DS31 | |
31 | | | Instruction | |<===============||| | +----------------+
32 | | | Register | | | |||
33 | +-------------------+ | ||| 100 RS> | +----------------+
34 | | Instruction Cycle | | ||| | | | | Return | |
35 | | | | | |||<=#=============| | Stack | |
36 | | 00 SMA_PC | | | |||===============>| | |
37 | | 01 PM> ,>IR ,PC++ | | ||| | 100 >RS --| | (cell 0) | |
38 | | 10 | | | +----------------+
39 | | 11 CL = IR[] | | | . | .
40 | | | | Bits | Instruction Format | +----------------+
41 | +-------------------+ | 15-13 xxx------------- xyz> | | | RS31 | |
42 | | | Control Logic | | 12-10 ---xxx---------- >xyz | +----------------+
43 | | | | | 9-7 | ------xxx------- ALU_OP
44 | +-------------------+ | 6 | ---------x------ Select Memory Address (SMA)
45 | 5-4 | ----------xx---- (unallocated)
46 | 3 | ------------x--- zero
47 | 2 | -------------x-- sign
48 | 1 | --------------x- carry
49 | 0 | ---------------x overflow

Figure 2.2: Complete architecture block diagram

6 2 Hardware

Table 2.1: Instruction Set Architecture (ISA)

Word | Binary OP code | OP code description
NOP | 000 000 000 0 00 0000 | No Operation
RESET | 111 111 111 1 11 1111 | Reset system
NO> | 000 | | No input source. High Z
PC> | 001 | | Program Counter out
PM> | 010 | | Program Memory out
MAR> | 011 | | Memory Address Register out
RS> | 100 | | Return stack out
TOS> | 101 | | POP Data Stack cell 0
DS1> | 110 | | POP Data Stack cell 1
DS2> | 111 | | POP Data Stack cell 2
>NO | ... 000 | | No output destination.
>PC | ... 001 | | Input to Program Counter
>PM | ... 010 | | Input to Program Memory
>MAR | ... 011 | | Input to Memory Address Register
>RS | ... 100 | | PUSH to Return stack
>TOS | ... 101 | | PUSH to Data Stack cell 0
>DS1 | ... 110 | | PUSH to Data Stack cell 1
>DS2 | ... 111 | | PUSH to Data Stack cell 2
ALU_NOP | ... ... 000 | | No ALU operation selected
ALU_ADD | ... ... 001 | | ALU addition
ALU_SUB | ... ... 010 | | ALU subtraction
ALU_AND | ... ... 011 | | ALU bitwise AND
ALU_OR | ... ... 100 | | ALU bitwise OR
ALU_XOR | ... ... 101 | | ALU bitwise XOR
ALU_« | ... ... 110 | | ALU bitshift left
ALU_» | ... ... 111 | | ALU bitchift right
SMA_MAR | | 0 .. .... | Select Memory Address from MAR
SMA_PC | | 1 .. .... | Select Memory Address from PC
| | xx .... | (unallocated)
if=0 | | 1... | Zero
if<0 | | 1.. | Sign
if_C | | 1. | Carry
if_OF | | 1 | Overflow

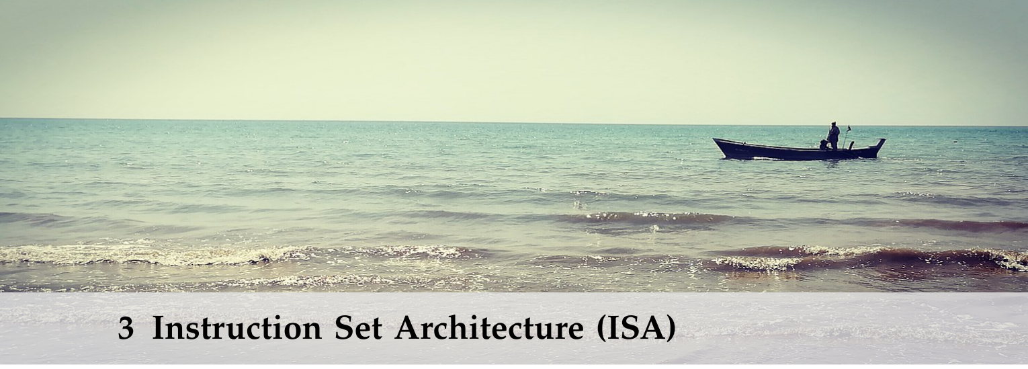
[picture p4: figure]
3 Instruction Set Architecture (ISA)

In This Chapter

you will learn

- First topic
- Second topic
- Third topic

you will be able to

- Task one
- Task two
- Task three

Hello, here is some text without a meaning. This text should show what a printed text will look like at this place. If you read this text, you will get no information. Really? Is there no information? Is there a difference between this text and some nonsense like “Huardest gefburn”? Kjift – not at all! A blind text like this gives you information about the selected font, how the letters are written and an impression of the look. This text should contain all letters of the alphabet and it should be written in of the original language. There is no need for special content, but the length of words should match the language.

## 3.1 ISA Explained

Explain what an ISA is.

## 3.2 Instruction cycle

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

8 3 Instruction Set Architecture (ISA)

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

## 3.3 Instruction Format

## 3.4 Instruction Timing

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

Figure 3.1: This is an example timing diagram that will be replaced by the real thing.

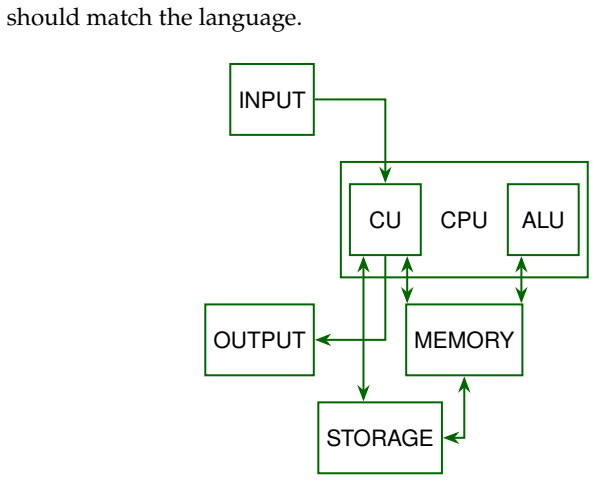
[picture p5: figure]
should match the language.; CPU; ALU; INPUT; OUTPUT; MEMORY; STORAGE

Hello, here is some text without a meaning. This text should show what a printed text will look like at this place. If you read this text, you will get no information. Really? Is there no information? Is there a difference between this text and some nonsense like “Huardest gefburn”? Kjift – not at all! A blind text like this gives you information about the selected font, how the letters are written and an impression of the look. This text should contain all letters of the alphabet and it should be written in of the original language. There is no need for special content, but the length of words should match the language. Hello, here is some text without a meaning. This text should show what a printed text will look like at this place. If you read this text, you will get no information. Really? Is there no information? Is there a difference between this text and some nonsense like “Huardest gefburn”? Kjift – not at all! A blind text like this gives you information about the selected font, how the letters are written and an impression of

3.4 Instruction Timing 9

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

RESET

Clock

Clock

Name

Signal | Text | Text | Text
Signal | Setup 00 | Setup 01 | Setup 10 | Setup 11
Signal | PC> ,>MAR | PM> ,>IR ,PC++ | PC> ,>MAR | LC=IR[]

Figure 3.2: This is an example timing diagram that will be replaced by the real thing.

### 1 _______________________________________________________________________ 2 RESET _/

3
4 | _______ | _______ | _______ | _______ | ____
5 | CLK | ____/ | \_______/ | \_______/ | \_______/ | \_______/
6 | ... | Execute 00 | | Execute 01 | | Execute 10 | | Execute 11 | |
7 | | PC> ,>MAR | | PM> ,>IR ,PC++| PC> ,>MAR | | CL=IR[] | | ...
8 | ____ | _______ | _______ | _______ | _______
9 | ~CLK | \_______/ | \_______/ | \_______/ | \_______/ | \____
10 | ... Setup 00 | | Setup 01 | | Setup 10 | | Setup 11 | | ...
11 | PC> ,>MAR | | PM> ,>IR ,PC++| PC> ,>MAR | | CL=IR[] | |

Figure 3.3: Instructions are executed. The contyrol logic is configured in between each step. Timing chart.

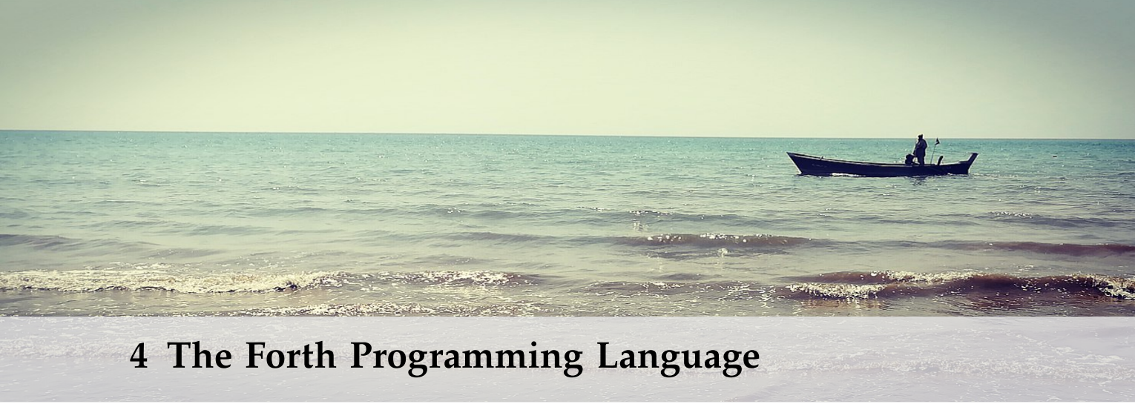
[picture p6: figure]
4 The Forth Programming Language

Add headings for these three columns: Address, Contents, Description

how are these items sorted? Alphabetical? Order of ap-pearance?

### 4.1 Dictionary Entry Format . . 11

### 4.2 The Forth Inner Interpreter . 13

### 4.5 The Forth Outter Interpreter 14

In This Chapter

you will learn

- First topic
- Second topic
- Third topic

you will be able to

- Task one
- Task two
- Task three

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

## 4.1 Dictionary Entry Format

Each word in Forth is defined by a dictionary entry immediate word.

The dictionary entry format is dependent upon the Forth implmentation, but a typical 16-bit Forth system will implement the structure described in Figure 4.1.

where
NFA is the address pointing to the first cell in the word’s name field, LFA is the address pointing to the word’s link pointer field,
CFA is the address pointing to the word’s code pointer field,
PFA is the address pointing to the first cell in the word’s parameter field,

12 4 The Forth Programming Language

Figure 4.1: Dictionary entry format.

Address | Content | Notes
15 14 | 0
Name Field Address (NFA) | p | n
NFA +1 | | name1

NFA +n | namen

name field

Link Field Address (LFA) | link pointer | link field
Code Field Addresss (CFA) | code pointer | code field
Parameter Field Address (PFA) | parameter1

PFA +c − 1 | parameterc

parameter field

This text uses the term parameter field. Other resources may use the term data field or other term.

p is the precedence bit (0,1),
n is the number of characters in the word’s name (e.g. DUPn = 3),

namen is the n

t ℎ character in the name, c is the number of cells in the parameter field, and

parameterc

is the c

t ℎ cell in the parameter field.

Each dictionary entry has a link pointer field, which holds an memory address pointing to the preceeding dictionary entry. By design, when the system searches for a word it starts at the end of the dictionary and works its way to the beginning by following these pointers. We call these addresses link pointers because they link the words together and to distinguish them from pointers with other purposes.

Each dictionary entry in the dictionary will share the same format for the name field, link field, and code field. The parameter field format depends on the word type. Constants, variables, colon-defined words, and any other type of defining word can have its own uniquie parameter field format.

The link pointer of a dictionary entry points to the name field of the previous word. The value of a link pointer is equal to the NFA of the pervious dictionary entry. The link pointer is an address pointing to the first cell of the previous dictionary entry’s name field. The LFA of a dictionary entry contains the NFA of the previous dictionary entry.i

Code pointer contains an address. This address is the "address of the instruction first executed when this type of word is executed." Starting Forth p. 222

Variable words. The code pushes the variable address onto the stack.

Constant words. The code pushes the contents of the constant onto the stack.

Colon defined words. The code executes the rest of the words in the colon definition.

In all the cases the code pointed to is called "tun-time code."

4.2 The Forth Inner Interpreter 13

The code address field is also known as the code pointer field. The data field is also known as the parameter field.

[2]: Brodie (1981), Starting FORTH

1: Use sidenotes if necessary

[3]: Loeliger (1981), Threaded Interpretive Languages

All words of a given type have the same code pointer.

code address is the address of the machine instruction the interpreter will load for execution, and
data is any data that is required for execution. todo[noline]Decide if the name field characters are 16-bit or 8-bit in the final implementation.

Precedence bit. 0 - address of the word gets compiled normally. 1 - The word is executed during compilation.

Are the characters in the name field limited to ASCII? Is there any technical reason they could not be any arbitrary 16-bit value? Maybe null would be a problem.

Leo Brodie’s Starting Forth[2] is good reading for this.

## 4.2 The Forth Inner Interpreter

This section gives a general explaination¹ of the chapter topic[3].

The word : causes the innter interpreter to enter compile mode. The name of the word is next, followed by the definition. The word ; causes the inner interpreter to exit compilation and reenter interpretation mode.

Example:

Listing 4.1: Definition of dup in Forth. 1 : square ( x -- x )

### 2 dup

3 *
4 :

This, of course, can be more conveniently written on a single line

: square ( x -- x )
dup * ;

## 4.3 Return Stack

The top of the return stack holds the return address. When a function call is made, the return address must be stored. If the call command is executed at address x, the return address x+1 is pushed to the top of the return stack.

## 4.4 Data Stack

The data styack is where temporary data is stored.

If a system has only one hardware stack, it shoulld be used for the data stack. Data manipulations are more common than function calls and the hardware stack is faster than memory access. The call stack will need to be stored in memory.

14 4 The Forth Programming Language

Margin notes can be used to explain de-tail or add reminders that would other-wise break the flow of the document. I think sidenotes are numbered while margin notes are not.

see BYO Assembler, Moving
Forth

For "colon words" (words compiled with the : word), the data field is a series of cells, each cell containing an address pointing to a word in the Forth dictionary.

The address interpreter (inner interpreter) copies the address stored in the address field into the interpreter pointer then executes the code at that address.

The interpreter does not keep track of or know about the type of word it is working with. The code linked to by the CFA is responsible for behaving appropriately.

## 4.5 The Forth Outter Interpreter

This an intermediate section. There will be several. each such section will cover a discrete topic within this chapter.

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

## 4.6 Forth Primitives

## 4.7 Metacompiler

## 4.8 Notes

Check out the YouTube channel learnmeabitcoin. The creator has a great video explaining SHA256 and another video explaining the Bitcoin Script stack machine.

Table 4.1: Example interpretation of a Forth word. This table would be paired with a code listing for the word. A column can be added for the return stack or other information. Exercises can be made in the style of fill-in-the-missing-item.

: times14 ( n1 — n2 ), n2 = 14 ∗ n1
Step | Data Stack | Interpret | Description
1 | n1 | 2 | 2 → TOS
2 | n1 2 | 3 | 3 → TOS
3 | n1 2 3 | 4 | 4 → TOS
4 | n1 2 3 4 | + | (x1 x2 — x3), x3 = x1 + x2
5 | n1 2 7 | * | (x1 x2 — x3), x3 = x1 ∗ x2
6 | n1 14 | * | (x1 x2 — x3), x3 = x1 ∗ x2
7 | n2 | ; | Return to interpreter

4.8 Notes | 15
1 | : literal | ( n -- | )
2 (Usage: : <name> ... [ n ] literal ... ; )
3 (Description: Compiles LIT and TOS number (n). When <name> is executed, n is placed on TOS.)

### 4 state @ if compile lit , then ; immediate

5
6 | :lit | ( | -- n | )

### 7 PM> ,>TOS ,PM-PC

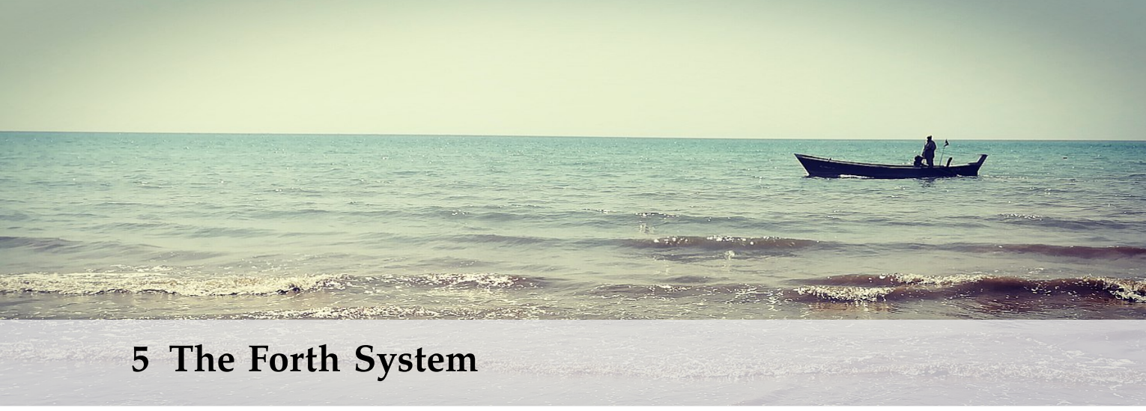
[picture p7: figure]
5 The Forth System

### 5.2 Forth System Parameters . 18

In This Chapter

you will learn

- what is the first topic
- how to identify the second topic
- best practices for the third topic

you will be able to

- perform the steps required to accomplish task one
- create a program that performs task two

This introduction gives the reader any context necessary to understand the proceeding sections in this chapter.

The contents of the ‘In This Chapter’ box should concrete. This should coorespond to a ‘Chapter Review’ section at the end of the chapter.

Illuminate any common obstacles for the reader. A few words of encour-agement are also welcomed.

## 5.1 Things Forth Does

### 5.1.1 System Operations

Note: the text interpreter handles input from terminal and files. It also handles compilation

Initialize system

Copy values into the correct location in memory. Set register values. Example: Read from memory the designated address for the stack pointer and load that into a particular register.

18 5 The Forth System

Interpret input stream

The outer interpreter (AKA text interpreter). The input stream could be a keyboard buffer, serial buffer, or other source.

Execution

’Innter interpreter.’ ’Address interpreter.’ Track which word is being executed and which to execute next. Jumping to machine code. Controls the flow of execution.

Error detection and handling

Usually by clearing the stack and returning control to the outer interpreter.

## 5.2 Forth System Parameters

Data Stack Pointer (DS), Return Stack Pointer (RS), Interpreter Pointer(IP), Word Pointer (W).

Data Stack Pointer. Holds the address of the top cell of the data stack. SP can be in memory or in a register. Register is better. This paragraph is true for systems that have the stack in RAM.

The data stack can be held in memory or in hardware stack provided by the CPU. The same is true of the return stack.

When using a hardware stack provided by the CPU, the Top of Stack (ToS) element is typically the only element that can be accessed by the data bus. Some microprocessors provide access to multiple cells. Three cells are a good number (Stack Computers?).

Return Stack Pointer (RS). Similar to the data stack. The data stack pointer and the data stack itself can beach be stored in memory. RS can be a hardware stack, but doing so does not provide the same performence gain as doind so with the data stack (source?).

During execution, a word may use the Return Stack for temkporary storage. Be careful!

Interpretative Pointer (IP). ’instruction pointer?’. Points to the code field (?) of the next word to be executed. Does thi depend on the system implementation? Can be stored in memory or a register.

Word Pointer (WP). Points to the word currently being executed. (Name field? Code field?).

5.3 Chapter Review 19

## 5.3 Chapter Review

Chapter Review

you have learned

- what is the first topic
- how to identify the second topic
- best practices for the third topic

you are able to

- perform the steps required to accomplish task one
- create a program that performs task two

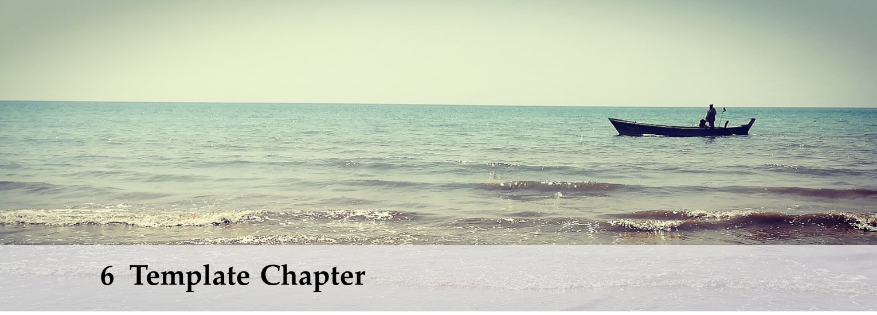
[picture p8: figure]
6 Template Chapter

1: After you have saved this document as a new file.

Add a list of elements

Remember
a kaobox can be used in the margins for special reminders)

### 6.1.4 Glossaries and Indicies . . 23

In This Chapter

you will learn

- what is the first topic
- how to identify the second topic
- best practices for the third topic

you will be able to

- perform the steps required to accomplish task one
- create a program that performs task two

This introduction gives the reader any context necessary to understand the proceeding sections in this chapter.

The contents of the ‘In This Chapter’ box should concrete. This should coorespond to a ‘Chapter Review’ section at the end of the chapter.

Illuminate any common obstacles for the reader. A few words of encour-agement are also welcomed.

## 6.1 Heaps of Examples

This section is fairly dense with examples. You can delete everything from here until the end of the page.¹

This section serves as an easy way to demonstrate‗ multiple graphical elements that can be used in this book.

Keep chapters, sections, and sub sections capitalized.

### 6.1.1 Margin Stuff

Generally, any text that would be written between parentheses would do well as a margin note. Keep the flow going.

‗ Like this footnote

22 6 Template Chapter

Notice that \subsubsection does not cause numbering.

Sections in Depth

Sections within a chapter can be \section, \subsection, or \subsubsection.

### 6.1.2 Figures and Tables

Listing 6.1: This Forth code does NOT
generate Table 6.1 | 1 | : square | ( x -- x )
2 ( Forth code that squares a number
3 dup * ;

This is an example of a table contained withing the main column of text.

Table 6.1: A useless table. | col1 | col2 | col3 | col4

Multiple
row
cell2 | cell3 | cell4
cell5 | cell6 | cell7
cell8 | cell9 | cell10

Multiple
row
cell2 | cell3 | cell4
cell5 | cell6 | cell7
cell8 | cell9 | cell10

We can also have full-width tables.

Table 6.2: A wide table with invented data about three people living in the UK. Note that wide figures and tables are centered and their caption also extends into the margin.

Name | Surname | Job | Salary | Age | Height | Country
Alice | Red | Writer | 4.000 £ | 34 | 167 cm | England
Bob | White | Bartender | 2.000 £ | 24 | 180 cm | Scotland
Drake | Green | Scientist | 4.000 £ | 26 | 175 cm | Wales

And full-width images.

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

6.1 Heaps of Examples 23

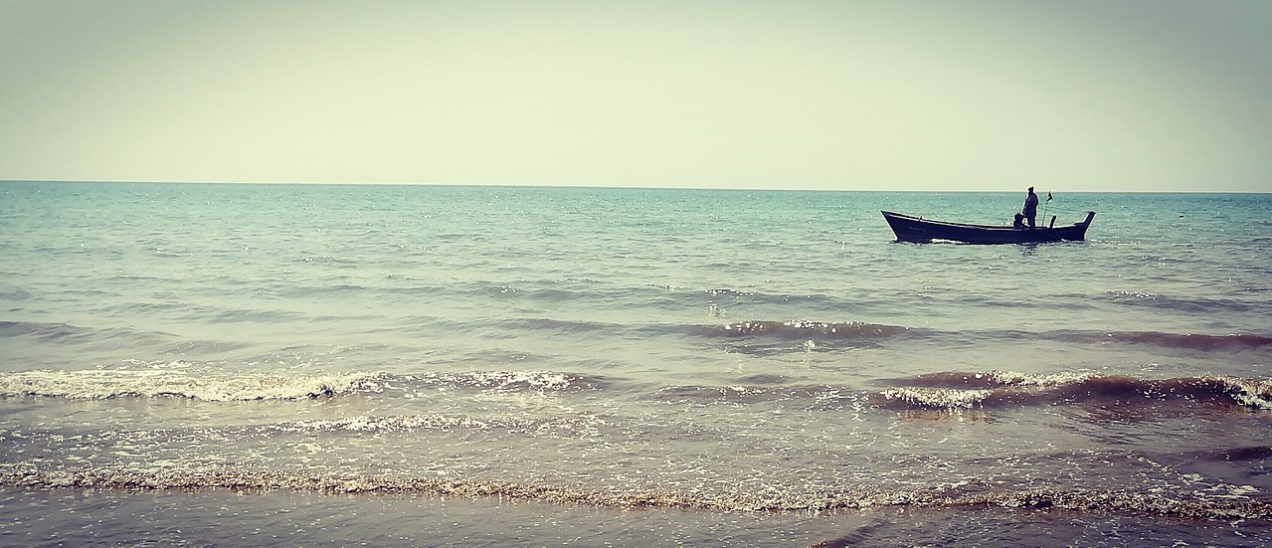
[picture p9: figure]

Figure 6.1: A wide seaside, and a wide caption. Credits: By Bushra Feroz, CC BY-SA 4.0, https://commons.wikimedia.org/w/index.php?
curid=68724647 (https://commons.wikimedia.org/w/index.php?curid=68724647)


Figure 6.2: A diagram produced by the Dot program and saved as a PNG file.

[4]: McZampleface (1999), The Great Book of Examples

### 6.1.3 Citations

Cite an author in the margin[4].

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

### 6.1.4 Glossaries and Indicies

### 6.1.5 Mathematics

The box below was created using the definition environment. Boxes are also provided by the theorem, proposition, lemma, corollary, example, remark, and exercise environments.

Definition 6.1.1 Let y be some function of x such that y = f (x)

where x and y are both variables in Definition 6.1.1.

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

24 6 Template Chapter

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

## 6.2 Chapter Review

Chapter Review

you have learned

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

you are able to

- perform the steps required to accomplish task one
- create a program that performs task two

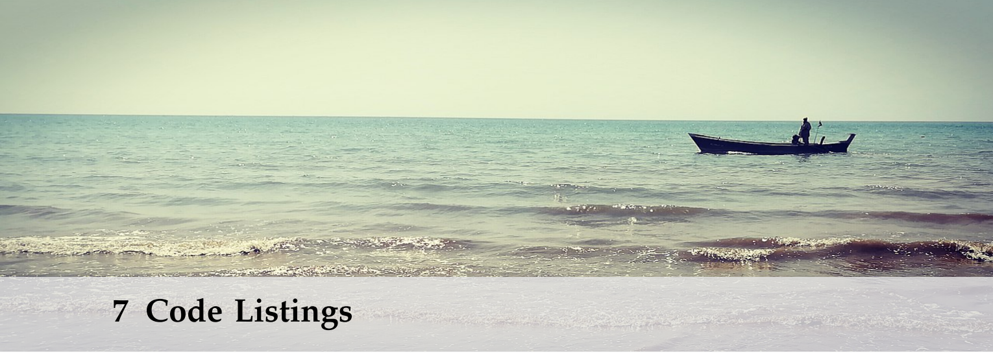
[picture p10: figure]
7 Code Listings

! ( n addr — ) Store n at addr.

1 | : ! | ( n addr -- )

### 2 TOS> ,>MAR 3 TOS> ,>PM

: ( — ) Colon definition. Create a new word. Usage: : <word> <...> ;

1 | : : | ( -- )

; ( — ) Terminate a colon definition. Resume interpretation. Usage: : <word> <...> ;

1 | : ; | ( -- )

>r ( n — ) Move n from data stack to return stack.

1 | : >r | ( n -- )

### 2 TOS> ,>RS

@ ( addr — n ) Put on TOS the value n stored at address addr.

1 | : @ | ( addr -- n )

### 2 TOS> ,>MAR 3 PM> ,>TOS

(create)

1 | : (create) | ( -- )

, Allot one cell of dictionary space. Store n at that cell’s address.

1 | : , | (n -- )

blk User variable. Located at address addr is the number of the block being interpreted.

1 | : blk | ( -- addr ) ( User variable. Located at address addr )
2 ( is the number )
3 ( of the block being interpreted )

here

26 | 7 Code Listings
1 | : here | ( -- addr ) ( Put on TOS the address of the next free )
2 ( cell in the dictionary )

interpret ( — ) Interpret the input string.

1 | : interpret | ( -- )

next ( — ) Compile the machine instructions which simulate the Forth machine’s next function. Must be used at the exit point of each code or ;code definition.

1 | : next | ( -- )

r> ( — n ) Move n from return stack to data stack.

1 | : r> | ( ( -- n )

### 2 RS> ,>TOS

# Template Appendix

A

## A.1 One section

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

## A.2 Another Section

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

# Bibliography

Works are listed in order of first citation.

[1] Jr. Philip J. Koopman. Stack Computers the New Wave. Ellis Horwood Limited, 1989 (cited on page 3).
[2] Leo Brodie. Starting FORTH. Prentice-Hall, Inc, 1981 (cited on page 13).
[3] R. G. Loeliger. Threaded Interpretive Languages. BYTE Publications, 1981 (cited on page 13).
[4] Mr. Example McZampleface. The Great Book of Examples. Place Holder Publishing, 1999 (cited on page 23).

Title: Implementing the Forth Inner Interpreter in High Level Forth Date: 2016-09 URL: http://www.euroforth.org/ef16/papers/hoffmann.pdf Abstract: This document defines a Forth threaded code (inner) interpreter written entirely in high level standard
Forth. For this it defines a specific threaded code structure of colon definitions, a compiler from high level
Forth to this threaded code and a corresponding inner interpreter to execute it. This inner interpreter can
run in a stepwise way and so gives the surrounding environment control of its execution behavior. A real time environment thus might slice the execution of threaded code in small pieces and provide an interactive command shell while still meeting its real time requirements. References: [1] A synchronous FORTH framework for hard real-time control, U. Hoffmann and A. Read, euroForth 2016 [2] Threaded Interpretive Languages: Their Design and Implementation, R. G. Loeliger, McGraw Hill, 1981 Notes: - This paper describes a Forth inner interpreter that runs inside a Forth system. This allows the Forth system to control the execution of the ’virtual’ interpreter. This is relevant to Real-Time Operating Systems (RTOS). - This paper is not relevant to the MacroProcessor Forth system

Title: Fig-Forth internals Date: 2021-09 URL: https://www.jimbrooks.org/archive/programming/forth/FIG-FORTH_internals.php Abstract: My notes from studying and modifying 8086 assembly code of FIG-FORTH. Describes how FIG-FORTH interpreter executes internally, how interpreting and compiling are virtually the same operation, ingenious solutions used to assemble FORTH interpreter. Also describes modifying FIG-FORTH to have direct-threaded code (DTC). Notes: - These notes are likely to be useful in understanding more low-level information. - This is not a walkthrough of the Forth system -"When FORTH starts, it begins executing machine-code of physical CPU. FORTH registers IP SP RP of FORTH virtual processor are initialized. System words COLD WARM ABORT are executed which completes initialization. ABORT executes QUIT" - "During execution of COLD which starts a FIG-FORTH system, QUIT creates command prompt. QUIT contains words QUERY INTERPRET. QUERY accepts commands, INTERPRET interprets or compiles them. QUIT emits OK message after INTERPRET returns."

# Notation

The next list describes several symbols that will be later used within the body of the document.

c | Speed of light in a vacuum inertial frame
ℎ | Planck constant
CFA | See Code Field Address
LFA | See Link Field Address
NFA | See Name Field Address
PFA | See Parameter Field Address

# Glossary

code field
code field description.
code pointer
The address of the code. Stored in a word’s code field. The Code Field Address is the addresss of the code field, not the address contained within the code field..
colon word
Colon-defined words have parameter fields that contain pointers to code fields in other words. These pointers are Code Field Addresses..
compile word
description.
CPU
Central Processor Unit.

data field
data see parameterField.
dictionary
dictionary description.
dictionary entry
is a set of data describing a Forth word.

immediate word
A word that has the IMMEDIATE bit set in its dictionary header. Is executed during interpretation. Is executed during compilation rather than compiled into a definition. Is executed during compilation and interpretation.

link field
link field description.
link field address
link field address description.

Machine-code word
A word that is directly executed by the CPU. Does not call other Forth words. May exit via a jump instruction to the address of NEXT or by including the contents of NEXT inline, thereby avoiding a jump instruction. Examples include the words NEXT EXECUTE BRANCH and EXIT ..

name field
name field description.
name field address
name field address description.

parameter field
the address of a word’s parameter field. The PFA points to the parameter field.. parameter field address
parameter field address description.

threaded- word
A word that contains other Forth words. May also contain machine-code words. Exits by calling the Forth word ; ..

Dictionary ===================

; "Semi-colon" Terminates a definition created by : .

1. Exits colon definition mode 2. Addes the definition to the dictionary 3. Enters interpretation mode

: ; ( – ) ( definition goes here ) ;

NEXT "Next" Terminates a code-word and jumps to the next instruction.

1. Fetch the Code Field Address (CFA), which is stored in a cell, which is pointed to by the Forth Instruction Pointer (IP) 2. Increment the Forth IP, which will then point to the proceeding cell, which contains the next Forth instruction 3. Jump to the fetched CFA

: NEXT ( – ) RS> ,>PC ,R–

Notes: - What is a cell? I think this is address of the code field of the proceeding Forth word. The IP always points to the next CFA to be executed. - Does the cell located at the CFA hold a machine instruction or is there a Forth dictionary word there? I think the contents of the cell pointed to by the CFA in the IP is always a machine instruction. I think the word INTERPRET handles the task of looking through the dictionary and determining the CFA of that word. The CFA should be the first cell of a word’s code field, which can be one or more cells.

# Alphabetical Index

instruction set architecture, 2

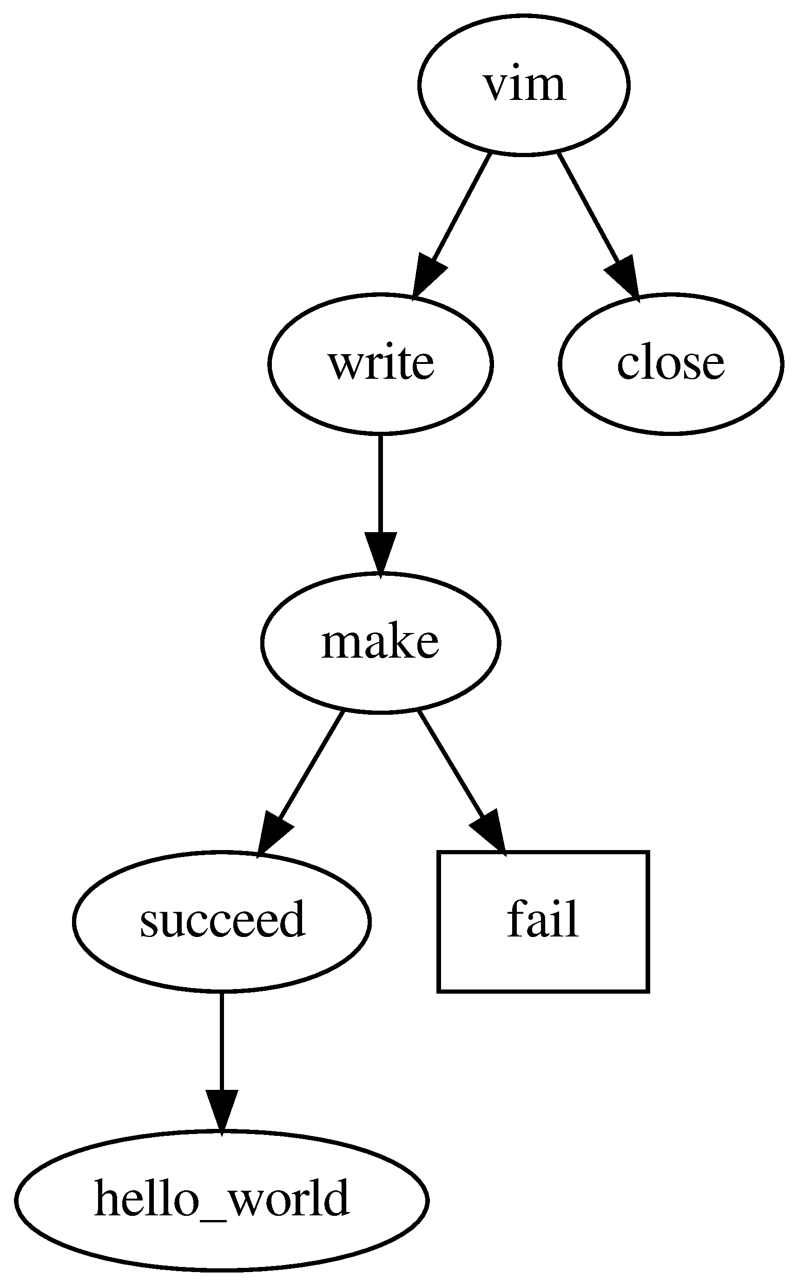
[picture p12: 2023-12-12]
book/images/output1.png

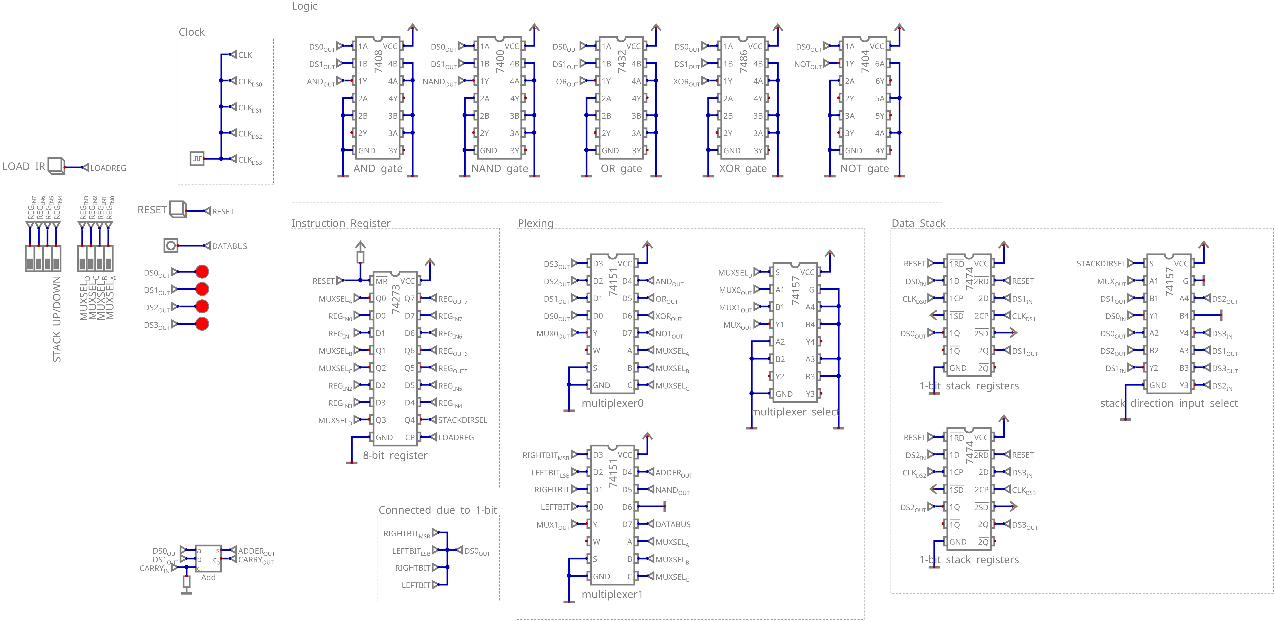
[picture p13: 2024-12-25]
vm-digital/bit-slice-chips.png

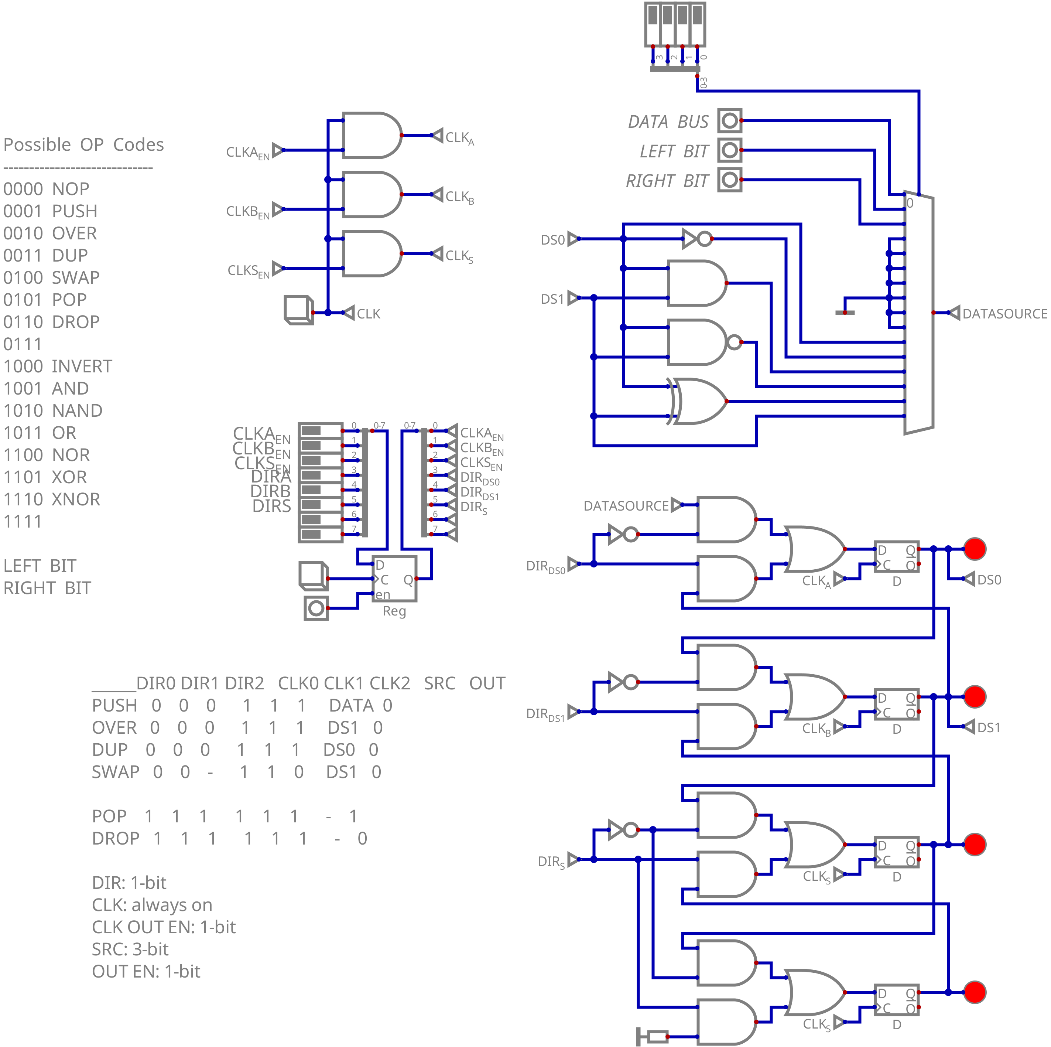
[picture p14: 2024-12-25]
vm-digital/bit-slice.png

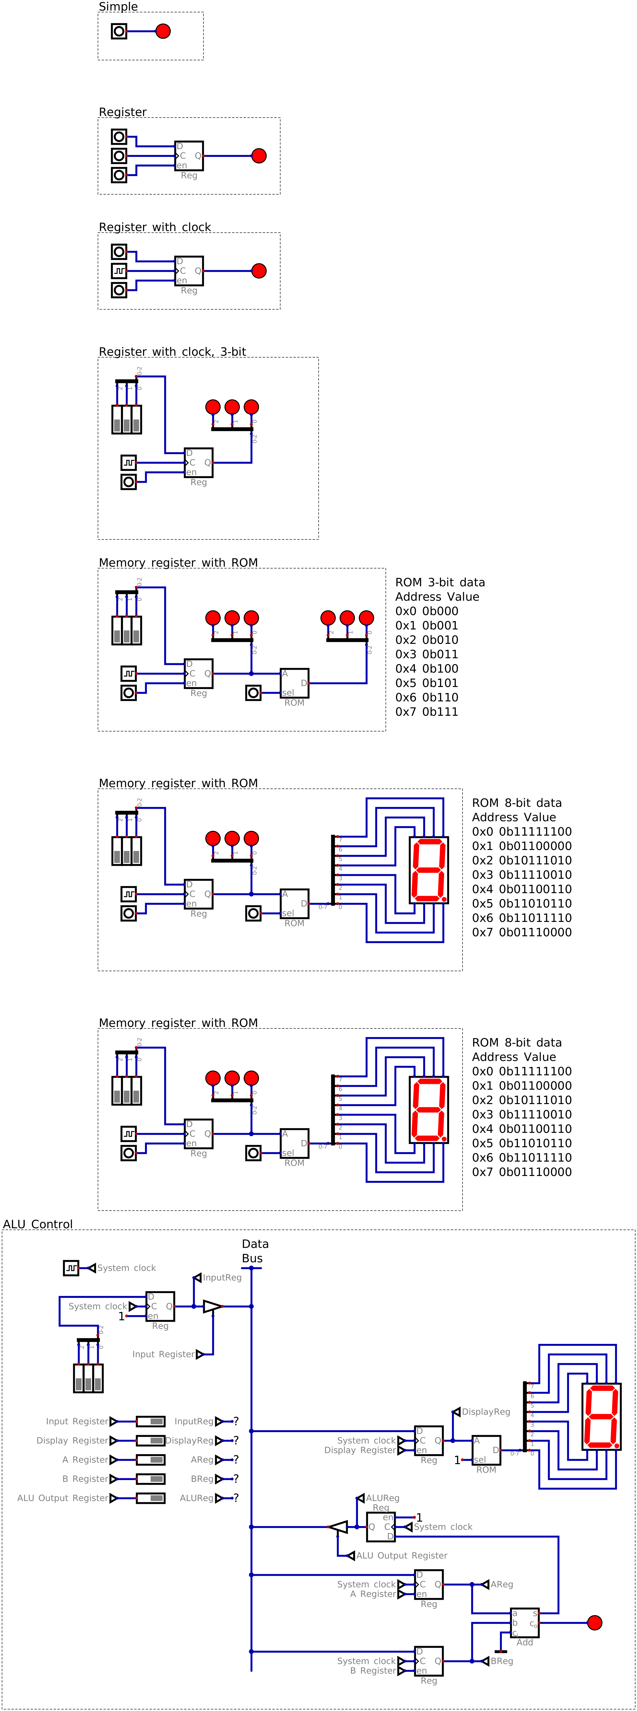
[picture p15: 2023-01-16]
sim/digipooper.png

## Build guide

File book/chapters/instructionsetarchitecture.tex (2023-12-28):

\setchapterimage{seaside}
\setchapterpreamble[u]{\margintoc}
\chapter{Instruction Set Architecture (ISA)}
\labch{isa}

%
% Key concepts and abilities
%==============================================================================
\begin{kaobox}[frametitle=In This Chapter]
you will learn
\begin{itemize}
	\item First topic
	\item Second topic
        \item Third topic
\end{itemize}

you will be able to
\begin{itemize}
        \item Task one
        \item Task two
        \item Task three
\end{itemize}
\end{kaobox}

% Introductory paragraph goes here
\blindtext

%
% Section: ISA Explained
%==============================================================================
\section{ISA Explained}
Explain what an ISA is.

%
% Section: Instruction cycle
%==============================================================================
\section{Instruction cycle}
\blindtext

%
% Section: Instruction Format
%==============================================================================
\section{Instruction Format}

%
% Section: Instruction Timing
%==============================================================================
\section{Instruction Timing}
\blindtext

\begin{figure}[hbt!]
\begin{tikzpicture}[
    myline/.style={draw=green!40!black, thick},
    box/.style={myline, minimum height=1cm, minimum width=1cm, font=\sffamily, inner sep=.3333em}, >=Stealth]

    \matrix (CPU) [matrix of nodes, inner ysep=3mm, nodes=box, myline, column sep=1mm]
        {|(CU)|CU & |[draw=none]|CPU & |(ALU)| ALU \\};
    \node[box, above left=5mm of CPU] (input) {INPUT};

    \node[box, below left=5mm of CPU] (output) {OUTPUT};
    \node[box, at=(CPU|-output)] (memory) {MEMORY};
    \node[box, below left=5mm of memory, anchor=north] (storage) {STORAGE};

    \draw[<->, myline] (storage)-|(memory);
    \draw[->,myline] (input)-|(CU);
    \draw[->,myline] (CU)|-(output);

    \draw[<->, myline] ($(CU.south west)!.2!(CU.south east)$) coordinate (aux)--(aux|-storage.north);
    \draw[<->, myline] ($(CU.south west)!.8!(CU.south east)$) coordinate (aux)--(aux|-memory.north);
    \draw[<->, myline] ($(ALU.south west)!.2!(ALU.south east)$) coordinate (aux)--(aux|-memory.north);
\end{tikzpicture}\caption[Timing diagram]{This is an example timing diagram that will be replaced by the real thing.}
\end{figure}

\blindtext
\blindtext

\begin{figure}[hbt!]
\begin{tikztimingtable}
    RESET & l 29{H} \\
    Clock & 3{10{C}} \\
    Clock & 3{10{C}} \\
    Name & 3{hLLLLh} \\
    Signal & 3{z8D{Text}z} \\
    Signal & {z8D{Setup 00}z} {z8D{Setup 01}z} {z8D{Setup 10}z} {z8D{Setup 11}z} \\
    Signal & {z8D{PC> ,>MAR}z} {z8D{PM> ,>IR ,PC++}z} {z8D{PC> ,>MAR}z} {z8D{LC=IR[]}z} \\
\end{tikztimingtable}
\caption[Timing diagram]{This is an example timing diagram that will be replaced by the real thing.}
\end{figure}

\begin{figure*}[h!]
\begin{lstlisting}
        _______________________________________________________________________
RESET _/       

           _______         _______         _______         _______         ____
 CLK  ____/       \_______/       \_______/       \_______/       \_______/    
      ... | Execute 00    | Execute 01    | Execute 10    | Execute 11   |
          |  PC> ,>MAR    | PM> ,>IR ,PC++| PC> ,>MAR     | CL=IR[]      | ...
      ____         _______         _______         _______         _______     
~CLK      \_______/       \_______/       \_______/       \_______/       \____
  ... Setup 00    | Setup 01      | Setup 10      | Setup 11      | ...
      PC> ,>MAR   | PM> ,>IR ,PC++| PC> ,>MAR     | CL=IR[]       |
\end{lstlisting}
\caption[Timing chart]{Instructions are executed. The contyrol logic is configured in between each step. Timing chart.}
\end{figure*}

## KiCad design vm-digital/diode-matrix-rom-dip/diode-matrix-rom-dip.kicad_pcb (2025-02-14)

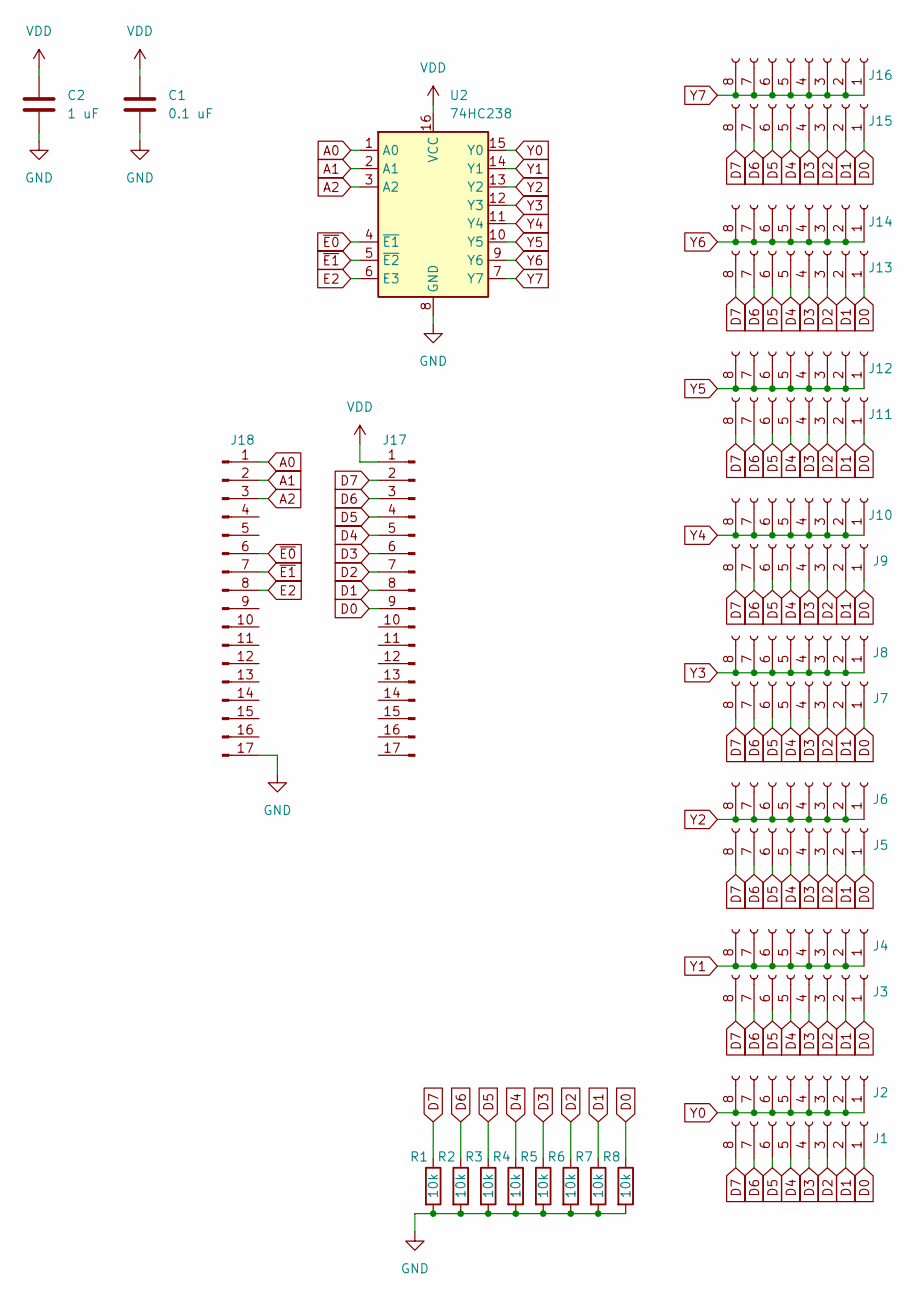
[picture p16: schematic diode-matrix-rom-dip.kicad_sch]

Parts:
C1: 0.1 uF; C_1206_3216Metric_Pad1.33x1.80mm_HandSolder
C2: 1 uF; C_1206_3216Metric_Pad1.33x1.80mm_HandSolder
J1, J2, J3, J4, J5, J6, J7, J8, J9, J10, J11, J12, J13, J14, J15, J16: Conn_01x08_Socket; PinSocket_1x08_P2.54mm_Vertical
J17, J18: Conn_01x17_Pin; PinHeader_1x17_P2.54mm_Vertical
R1, R2, R3, R4, R5, R6, R7, R8: 10k; R_0201_0603Metric
U2: 74HC238; DIP-16_W7.62mm

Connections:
A0: J18.1, U2.1 (A0)
A1: J18.2, U2.2 (A1)
A2: J18.3, U2.3 (A2)
D0: J1.1, J3.1, J5.1, J7.1, J9.1, J11.1, J13.1, J15.1, J17.9, R8.1
D1: J1.2, J3.2, J5.2, J7.2, J9.2, J11.2, J13.2, J15.2, J17.8, R7.1
D2: J1.3, J3.3, J5.3, J7.3, J9.3, J11.3, J13.3, J15.3, J17.7, R6.1
D3: J1.4, J3.4, J5.4, J7.4, J9.4, J11.4, J13.4, J15.4, J17.6, R5.1
D4: J1.5, J3.5, J5.5, J7.5, J9.5, J11.5, J13.5, J15.5, J17.5, R4.1
D5: J1.6, J3.6, J5.6, J7.6, J9.6, J11.6, J13.6, J15.6, J17.4, R3.1
D6: J1.7, J3.7, J5.7, J7.7, J9.7, J11.7, J13.7, J15.7, J17.3, R2.1
D7: J1.8, J3.8, J5.8, J7.8, J9.8, J11.8, J13.8, J15.8, J17.2, R1.1
E2: J18.8, U2.6 (E3)
GND: C1.2, C2.2, J18.17, R1.2, R2.2, R3.2, R4.2, R5.2, R6.2, R7.2, R8.2, U2.8 (GND)
VDD: C1.1, C2.1, J17.1, U2.16 (VCC)
Y0: J2.1, J2.2, J2.3, J2.4, J2.5, J2.6, J2.7, J2.8, U2.15 (Y0)
Y1: J4.1, J4.2, J4.3, J4.4, J4.5, J4.6, J4.7, J4.8, U2.14 (Y1)
Y2: J6.1, J6.2, J6.3, J6.4, J6.5, J6.6, J6.7, J6.8, U2.13 (Y2)
Y3: J8.1, J8.2, J8.3, J8.4, J8.5, J8.6, J8.7, J8.8, U2.12 (Y3)
Y4: J10.1, J10.2, J10.3, J10.4, J10.5, J10.6, J10.7, J10.8, U2.11 (Y4)
Y5: J12.1, J12.2, J12.3, J12.4, J12.5, J12.6, J12.7, J12.8, U2.10 (Y5)
Y6: J14.1, J14.2, J14.3, J14.4, J14.5, J14.6, J14.7, J14.8, U2.9 (Y6)
Y7: J16.1, J16.2, J16.3, J16.4, J16.5, J16.6, J16.7, J16.8, U2.7 (Y7)
~E0: J18.6, U2.4 (~E1)
~E1: J18.7, U2.5 (~E2)

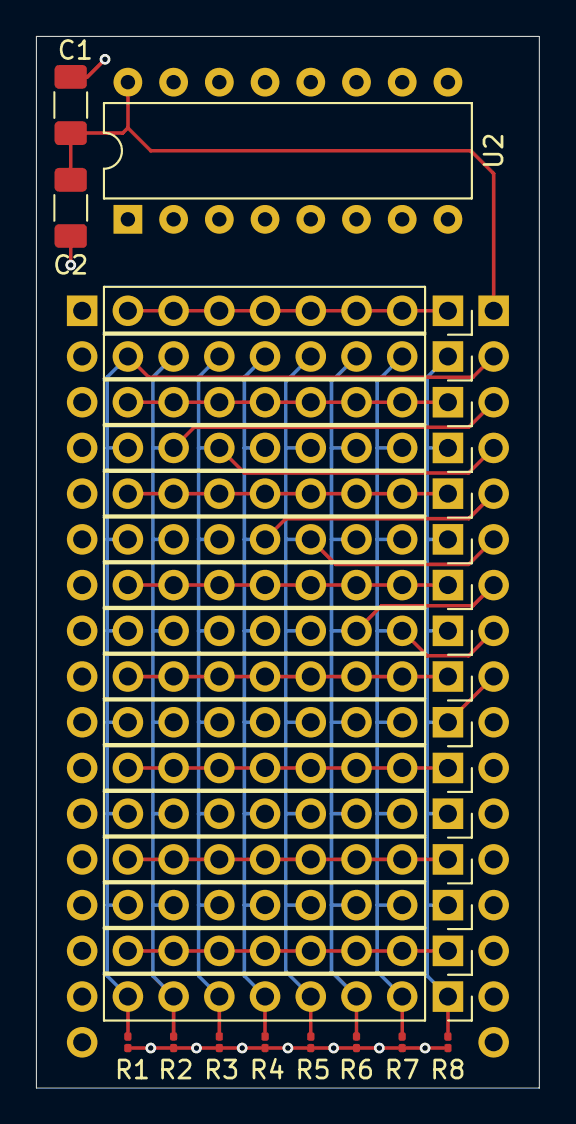
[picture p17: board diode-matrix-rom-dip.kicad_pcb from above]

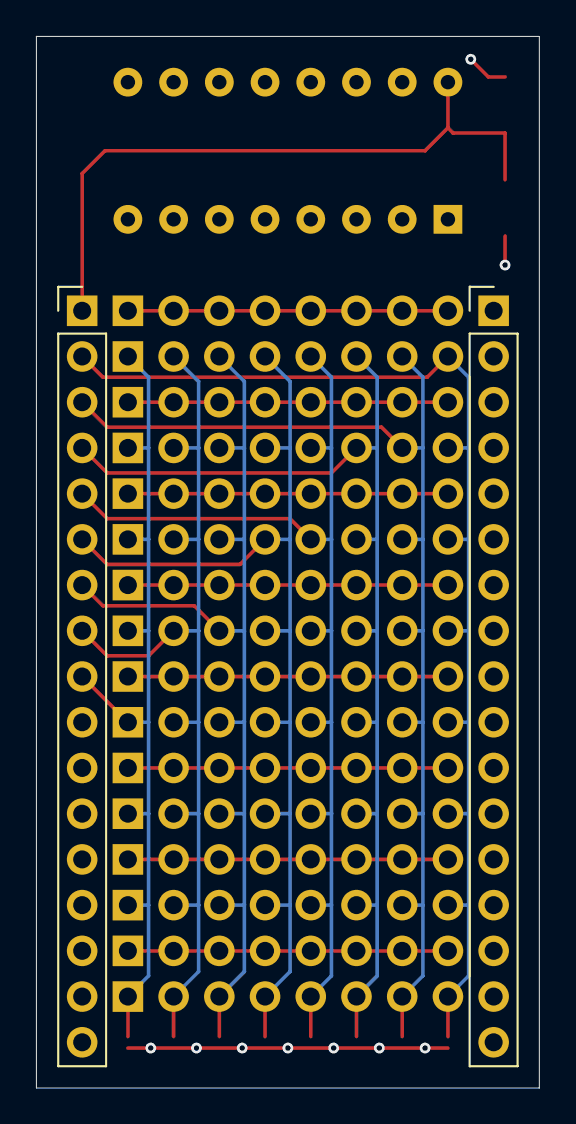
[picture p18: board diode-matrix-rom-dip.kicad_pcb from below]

Board: 4 copper layers, 27.9 x 58.4 mm, 29 parts (2 on the bottom side), 24 nets.

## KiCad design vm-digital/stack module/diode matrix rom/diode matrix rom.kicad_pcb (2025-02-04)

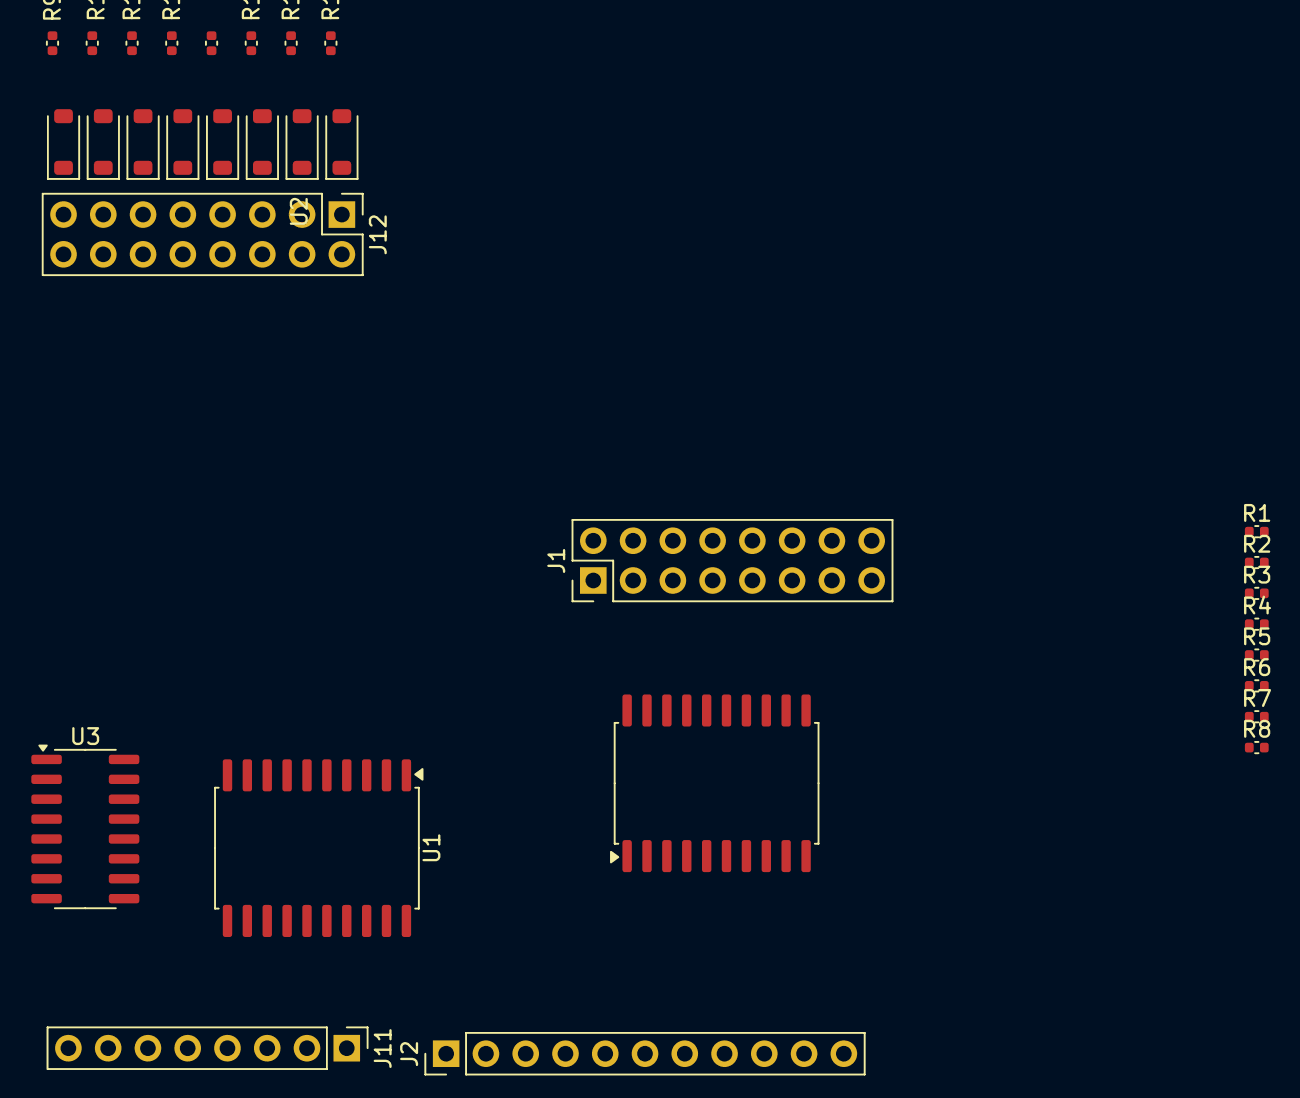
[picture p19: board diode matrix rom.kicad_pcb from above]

Board: 2 copper layers, 31 parts (0 on the bottom side), 47 nets, no tracks yet.

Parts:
D1, D2, D3, D4, D5, D6, D7, D8: D; D_SOD-123
J1, J12: DIN41612_02x16_AB; PinHeader_2x08_P2.54mm_Vertical
J2: Conn_01x11_Pin; PinHeader_1x11_P2.54mm_Vertical
J11: Conn_01x08_Pin; PinHeader_1x08_P2.54mm_Vertical
R1, R2, R3, R4, R5, R6, R7, R8, R9, R10, R11, R12, R13, R14, R15, R16: 10k; C_0402_1005Metric
U1: 74LS540; SOIC-20W_7.5x12.8mm_P1.27mm
U2: 74HC688; SOIC-20W_7.5x12.8mm_P1.27mm
U3: 74HC238; SOIC-16_3.9x9.9mm_P1.27mm

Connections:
B0: D1.2 (A), R16.2, U1.2 (A0)
B1: D2.2 (A), R15.2, U1.3 (A1)
B2: D4.2 (A), R14.2, U1.4 (A2)
B3: D3.2 (A), R13.2, U1.5 (A3)
B4: D8.2 (A), R12.2, U1.6 (A4)
B5: D7.2 (A), R11.2, U1.7 (A5)
B6: D6.2 (A), R10.2, U1.8 (A6)
B7: D5.2 (A), R9.2, U1.9 (A7)
GND: R1.1, R2.1, R3.1, R4.1, R5.1, R6.1, R7.1, R8.1, U1.10 (GND), U2.10 (GND), U3.8 (GND)
unnamed: D1.1 (K), J12.1
unnamed: D2.1 (K), J12.3
unnamed: D3.1 (K), J12.7
unnamed: D4.1 (K), J12.5
unnamed: D5.1 (K), J12.15
unnamed: D6.1 (K), J12.13
unnamed: D7.1 (K), J12.11
unnamed: D8.1 (K), J12.9
unnamed: J1.2, R1.2, U2.2 (P0)
unnamed: J1.4, R2.2, U2.4 (P1)
unnamed: J1.6, R3.2, U2.6 (P2)
unnamed: J1.8, R4.2, U2.8 (P3)
unnamed: J1.10, R5.2, U2.11 (P4)
unnamed: J1.12, R6.2, U2.13 (P5)
unnamed: J1.14, R7.2, U2.15 (P6)
unnamed: J1.16, R8.2, U2.17 (P7)
unnamed: J2.1, U3.1 (A0)
unnamed: J2.2, U3.2 (A1)
unnamed: J2.3, U3.3 (A2)
unnamed: J2.4, U2.3 (R0)
unnamed: J2.5, U2.5 (R1)
unnamed: J2.6, U2.7 (R2)
unnamed: J2.7, U2.9 (R3)
unnamed: J2.8, U2.12 (R4)
unnamed: J2.9, U2.14 (R5)
unnamed: J2.10, U2.16 (R6)
unnamed: J2.11, U2.18 (R7)
unnamed: J11.1, U1.18 (Y0)
unnamed: J11.2, U1.17 (Y1)
unnamed: J11.3, U1.16 (Y2)
unnamed: J11.4, U1.15 (Y3)
unnamed: J11.5, U1.14 (Y4)
unnamed: J11.6, U1.13 (Y5)
unnamed: J11.7, U1.12 (Y6)
unnamed: J11.8, U1.11 (Y7)
unnamed: U1.1 (G1), U1.19 (G2), U2.19 (P=R), U3.4 (~E0), U3.5 (~E1)
VDD: J1.1, J1.3, J1.5, J1.7, J1.9, J1.11, J1.13, J1.15, R9.1, R10.1, R11.1, R12.1, R13.1, R14.1, R15.1, R16.1, U1.20 (VCC), U2.20 (VCC), U3.6 (E2), U3.16 (VCC)
W0: J12.2, J12.4, J12.6, J12.8, J12.10, J12.12, J12.14, J12.16, U3.15 (~Y0)

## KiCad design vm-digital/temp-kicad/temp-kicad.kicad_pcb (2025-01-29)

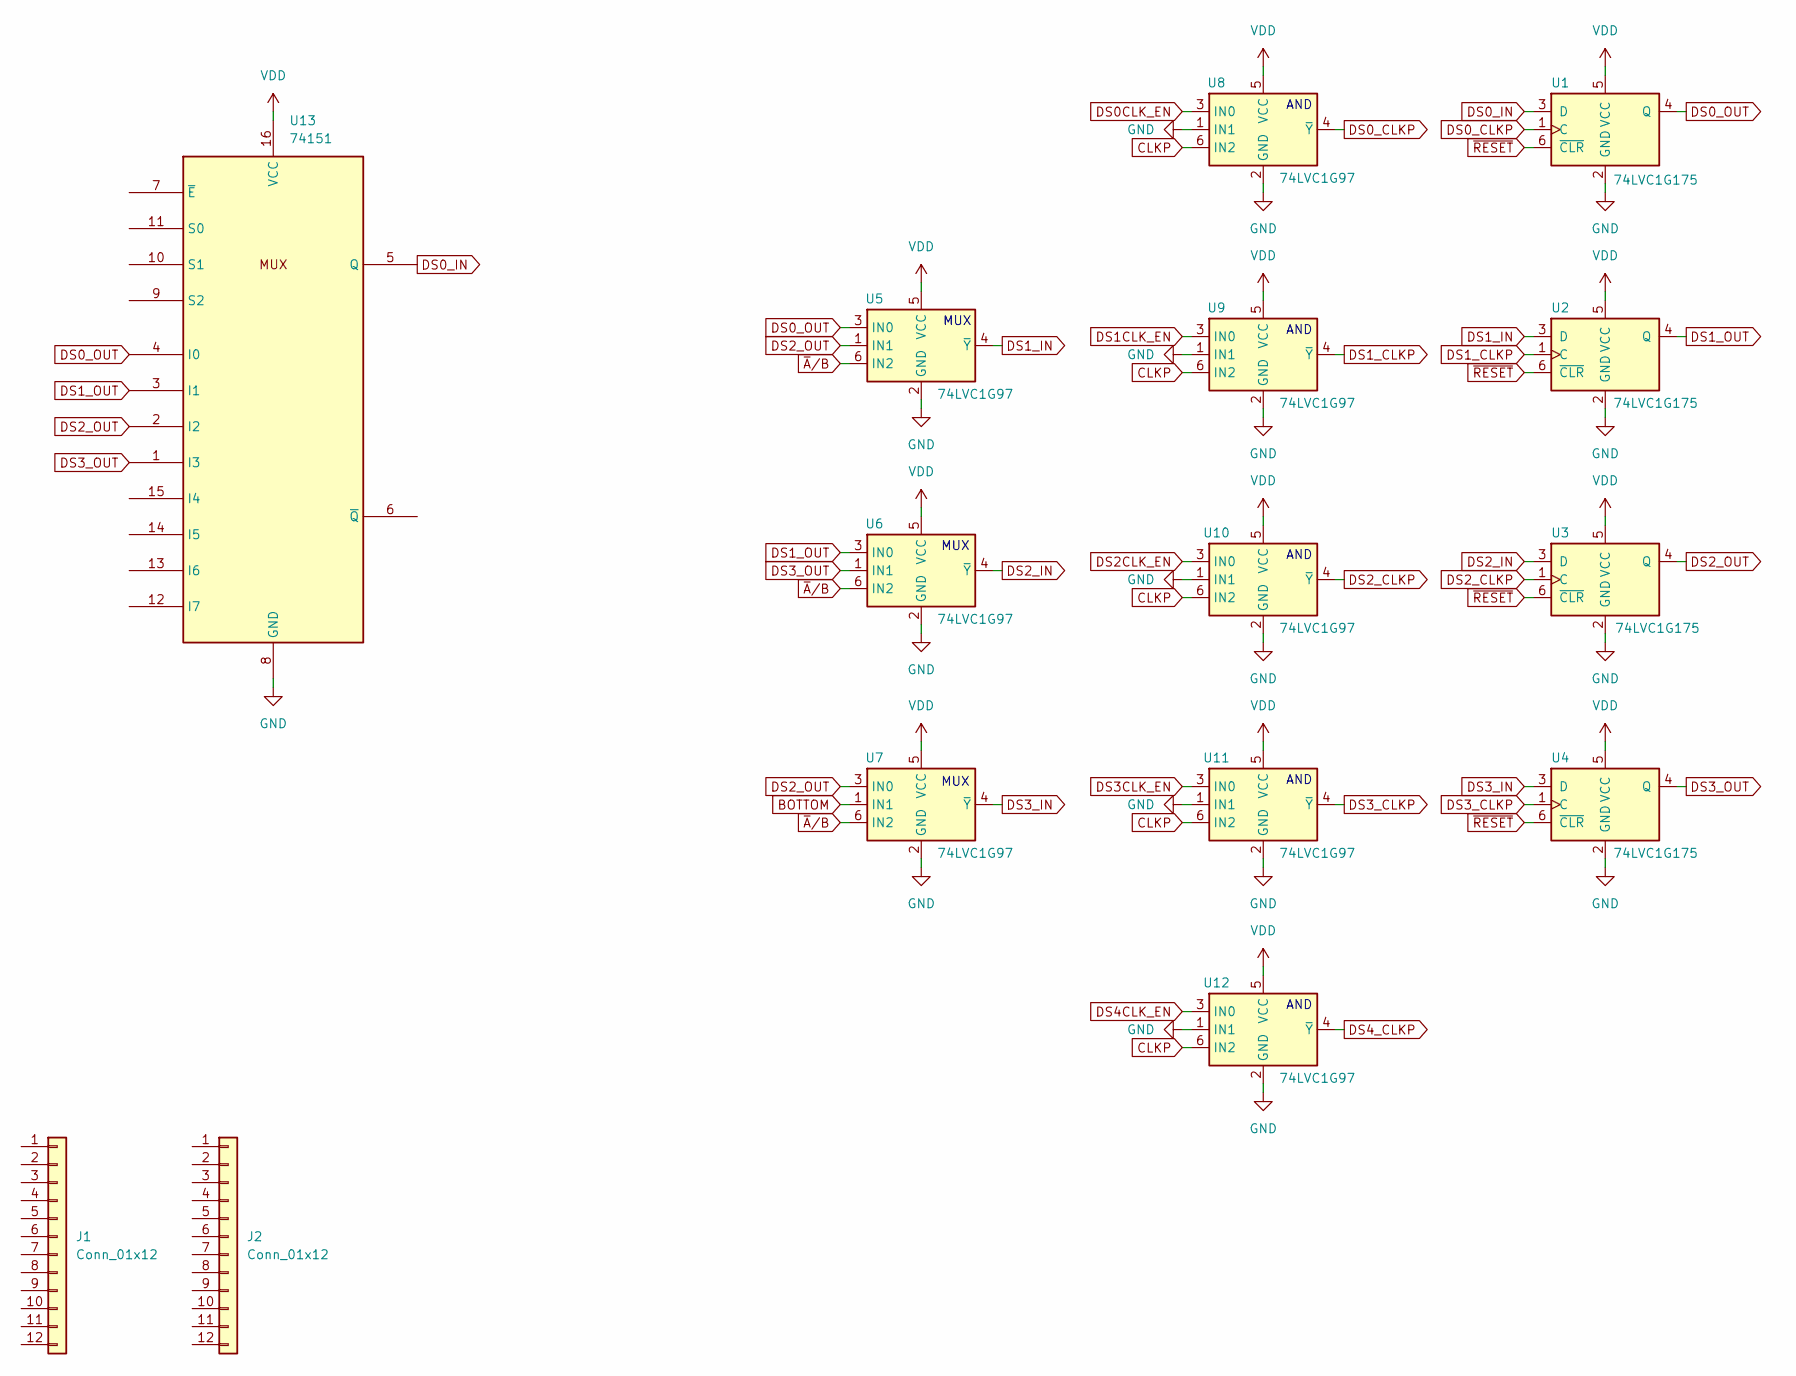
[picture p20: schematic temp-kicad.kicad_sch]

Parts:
J1, J2: Conn_01x12; PinHeader_1x12_P2.54mm_Vertical
U1, U2, U3, U4: 74LVC1G175; SOT-23-6_Handsoldering
U5, U6, U7, U8, U9, U10, U11, U12: 74LVC1G97; SOT-23-6_Handsoldering
U13: 74151; SOIC-16_3.9x9.9mm_P1.27mm

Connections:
BOTTOM: U7.1 (IN1)
CLKP: U8.6 (IN2), U9.6 (IN2), U10.6 (IN2), U11.6 (IN2), U12.6 (IN2)
DS0CLK_EN: U8.3 (IN0)
DS0_CLKP: U1.1 (C), U8.4 (~Y)
DS0_IN: U1.3 (D), U13.5 (Q)
DS0_OUT: U1.4 (Q), U5.3 (IN0), U13.4 (I0)
DS1CLK_EN: U9.3 (IN0)
DS1_CLKP: U2.1 (C), U9.4 (~Y)
DS1_IN: U2.3 (D), U5.4 (~Y)
DS1_OUT: U2.4 (Q), U6.3 (IN0), U13.3 (I1)
DS2CLK_EN: U10.3 (IN0)
DS2_CLKP: U3.1 (C), U10.4 (~Y)
DS2_IN: U3.3 (D), U6.4 (~Y)
DS2_OUT: U3.4 (Q), U5.1 (IN1), U7.3 (IN0), U13.2 (I2)
DS3CLK_EN: U11.3 (IN0)
DS3_CLKP: U4.1 (C), U11.4 (~Y)
DS3_IN: U4.3 (D), U7.4 (~Y)
DS3_OUT: U4.4 (Q), U6.1 (IN1), U13.1 (I3)
DS4CLK_EN: U12.3 (IN0)
DS4_CLKP: U12.4 (~Y)
GND: U1.2 (GND), U2.2 (GND), U3.2 (GND), U4.2 (GND), U5.2 (GND), U6.2 (GND), U7.2 (GND), U8.1 (IN1), U8.2 (GND), U9.1 (IN1), U9.2 (GND), U10.1 (IN1), U10.2 (GND), U11.1 (IN1), U11.2 (GND), U12.1 (IN1), U12.2 (GND), U13.8 (GND)
VDD: U1.5 (VCC), U2.5 (VCC), U3.5 (VCC), U4.5 (VCC), U5.5 (VCC), U6.5 (VCC), U7.5 (VCC), U8.5 (VCC), U9.5 (VCC), U10.5 (VCC), U11.5 (VCC), U12.5 (VCC), U13.16 (VCC)
~A/B: U5.6 (IN2), U6.6 (IN2), U7.6 (IN2)
~RESET: U1.6 (~CLR), U2.6 (~CLR), U3.6 (~CLR), U4.6 (~CLR)

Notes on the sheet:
MUX
AND

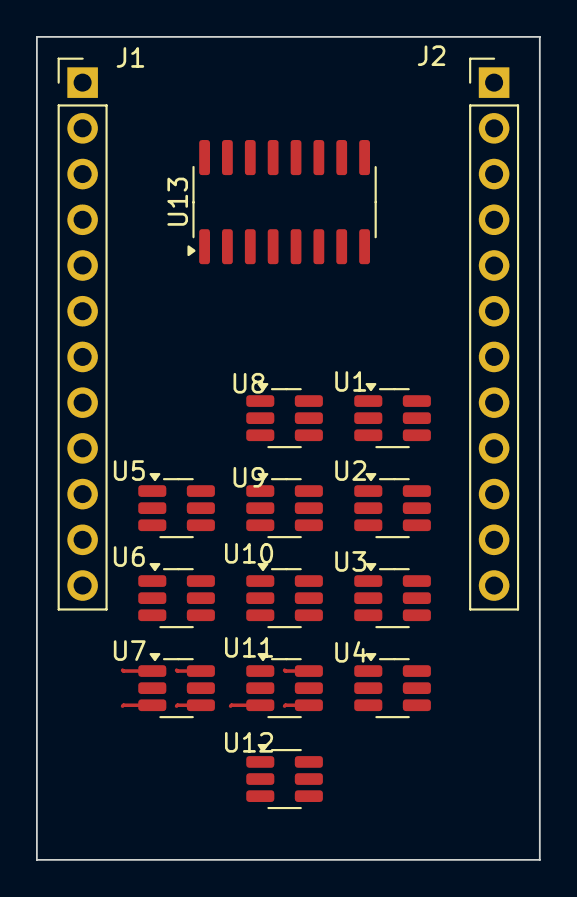
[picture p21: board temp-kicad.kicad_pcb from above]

Board: 4 copper layers, 27.9 x 45.7 mm, 15 parts (0 on the bottom side), 17 nets.

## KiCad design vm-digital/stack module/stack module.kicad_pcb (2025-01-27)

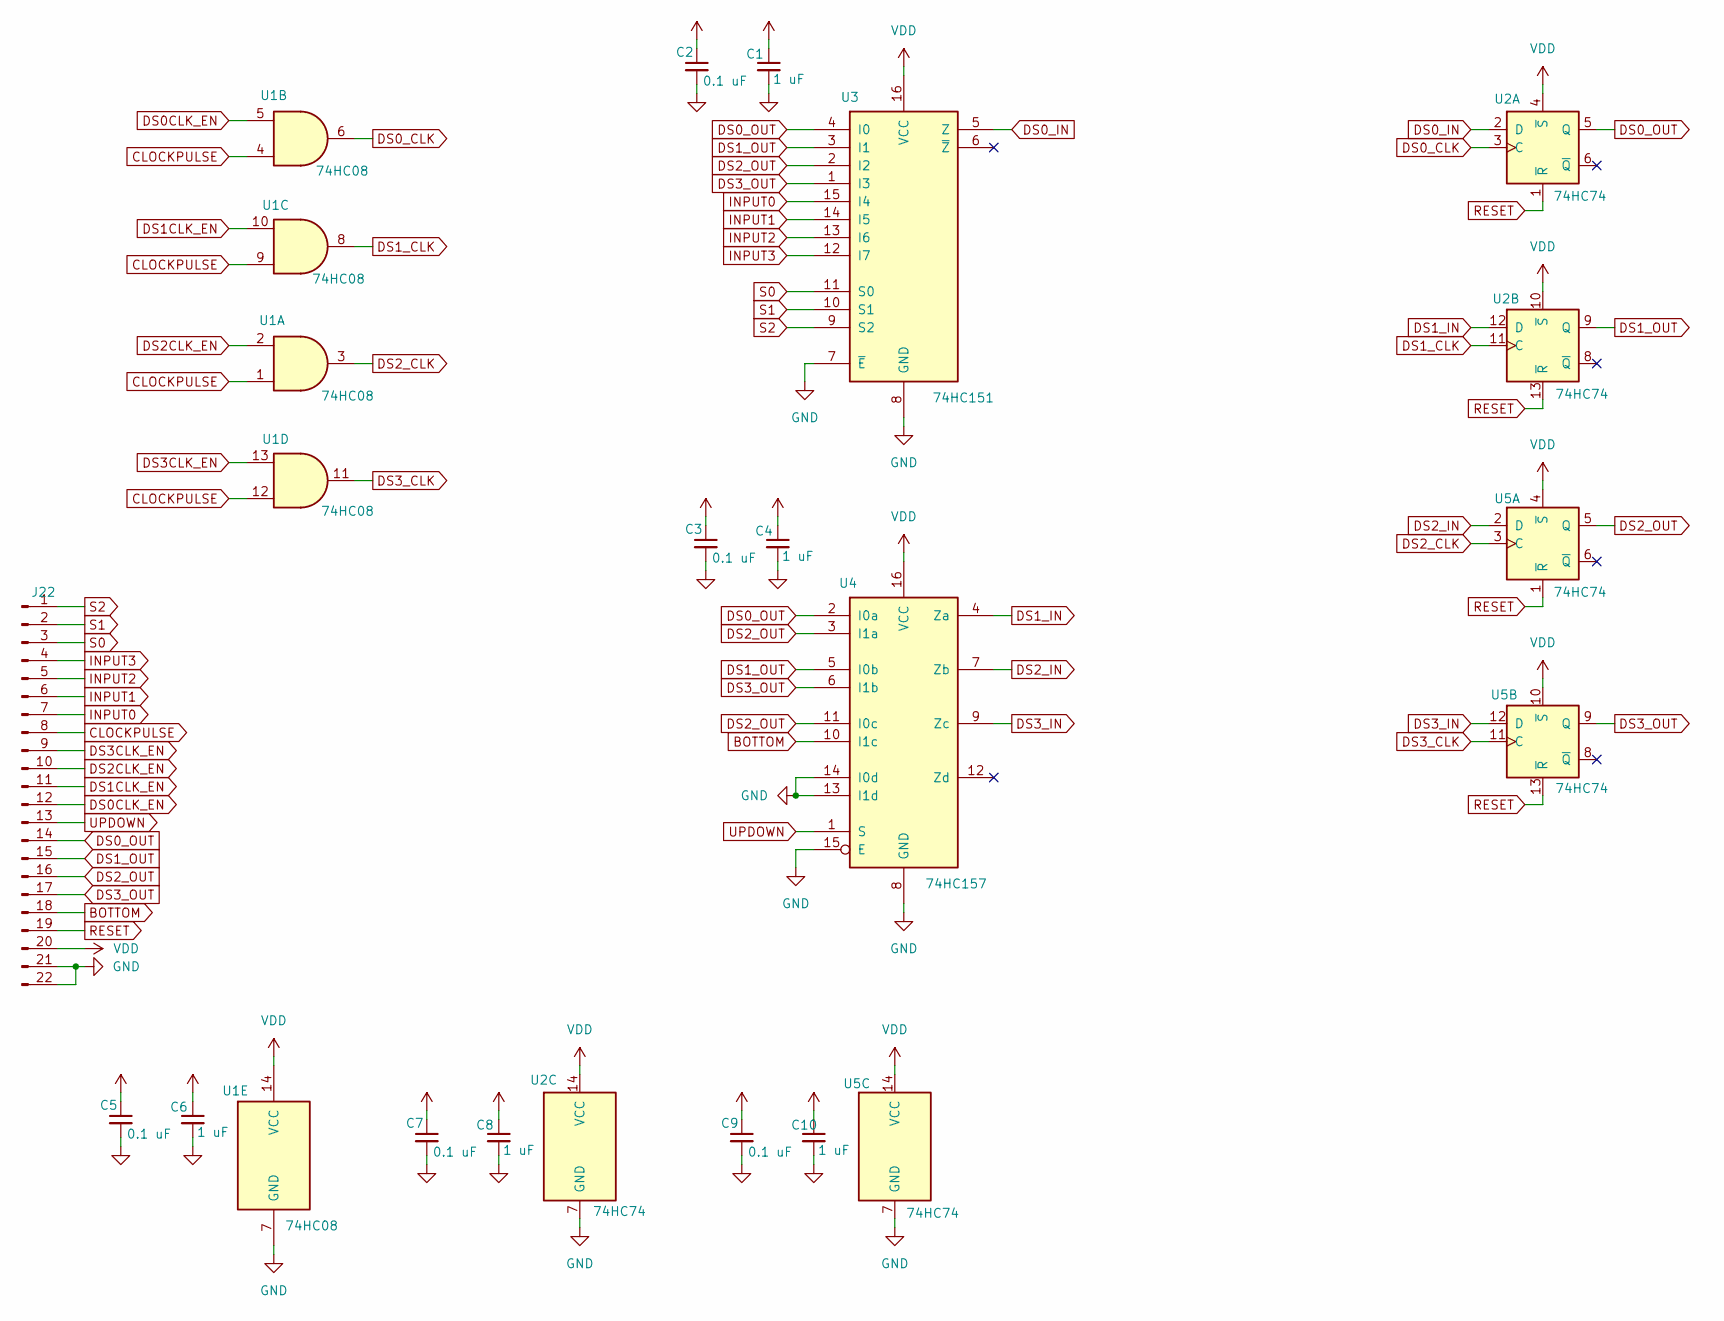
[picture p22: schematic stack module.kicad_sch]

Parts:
C1, C4, C6, C8, C10: 1 uF; C_1206_3216Metric_Pad1.33x1.80mm_HandSolder
C2, C3, C5, C7, C9: 0.1 uF; C_1206_3216Metric_Pad1.33x1.80mm_HandSolder
J22: Conn_01x22_Pin; PinHeader_1x22_P2.54mm_Vertical
U1: 74HC08; DIP-14_W7.62mm_Socket_LongPads
U2, U5: 74HC74; DIP-14_W7.62mm_Socket_LongPads
U3: 74HC151; DIP-16_W7.62mm_Socket_LongPads
U4: 74HC157; DIP-16_W7.62mm_Socket_LongPads

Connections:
BOTTOM: J22.18, U4.10 (I1c)
CLOCKPULSE: J22.8, U1.1, U1.4, U1.9, U1.12
DS0CLK_EN: J22.12, U1.5
DS0_CLK: U1.6, U2.3 (C)
DS0_IN: U2.2 (D), U3.5 (Z)
DS0_OUT: J22.14, U2.5 (Q), U3.4 (I0), U4.2 (I0a)
DS1CLK_EN: J22.11, U1.10
DS1_CLK: U1.8, U2.11 (C)
DS1_IN: U2.12 (D), U4.4 (Za)
DS1_OUT: J22.15, U2.9 (Q), U3.3 (I1), U4.5 (I0b)
DS2CLK_EN: J22.10, U1.2
DS2_CLK: U1.3, U5.3 (C)
DS2_IN: U4.7 (Zb), U5.2 (D)
DS2_OUT: J22.16, U3.2 (I2), U4.3 (I1a), U4.11 (I0c), U5.5 (Q)
DS3CLK_EN: J22.9, U1.13
DS3_CLK: U1.11, U5.11 (C)
DS3_IN: U4.9 (Zc), U5.12 (D)
DS3_OUT: J22.17, U3.1 (I3), U4.6 (I1b), U5.9 (Q)
GND: C1.2, C2.2, C3.2, C4.2, C5.2, C6.2, C7.2, C8.2, C9.2, C10.2, J22.21, J22.22, U1.7 (GND), U2.7 (GND), U3.7 (~E), U3.8 (GND), U4.8 (GND), U4.13 (I1d), U4.14 (I0d), U4.15 (E), U5.7 (GND)
INPUT0: J22.7, U3.15 (I4)
INPUT1: J22.6, U3.14 (I5)
INPUT2: J22.5, U3.13 (I6)
INPUT3: J22.4, U3.12 (I7)
RESET: J22.19, U2.1 (~R), U2.13 (~R), U5.1 (~R), U5.13 (~R)
S0: J22.3, U3.11 (S0)
S1: J22.2, U3.10 (S1)
S2: J22.1, U3.9 (S2)
UPDOWN: J22.13, U4.1 (S)
VDD: C1.1, C2.1, C3.1, C4.1, C5.1, C6.1, C7.1, C8.1, C9.1, C10.1, J22.20, U1.14 (VCC), U2.4 (~S), U2.10 (~S), U2.14 (VCC), U3.16 (VCC), U4.16 (VCC), U5.4 (~S), U5.10 (~S), U5.14 (VCC)

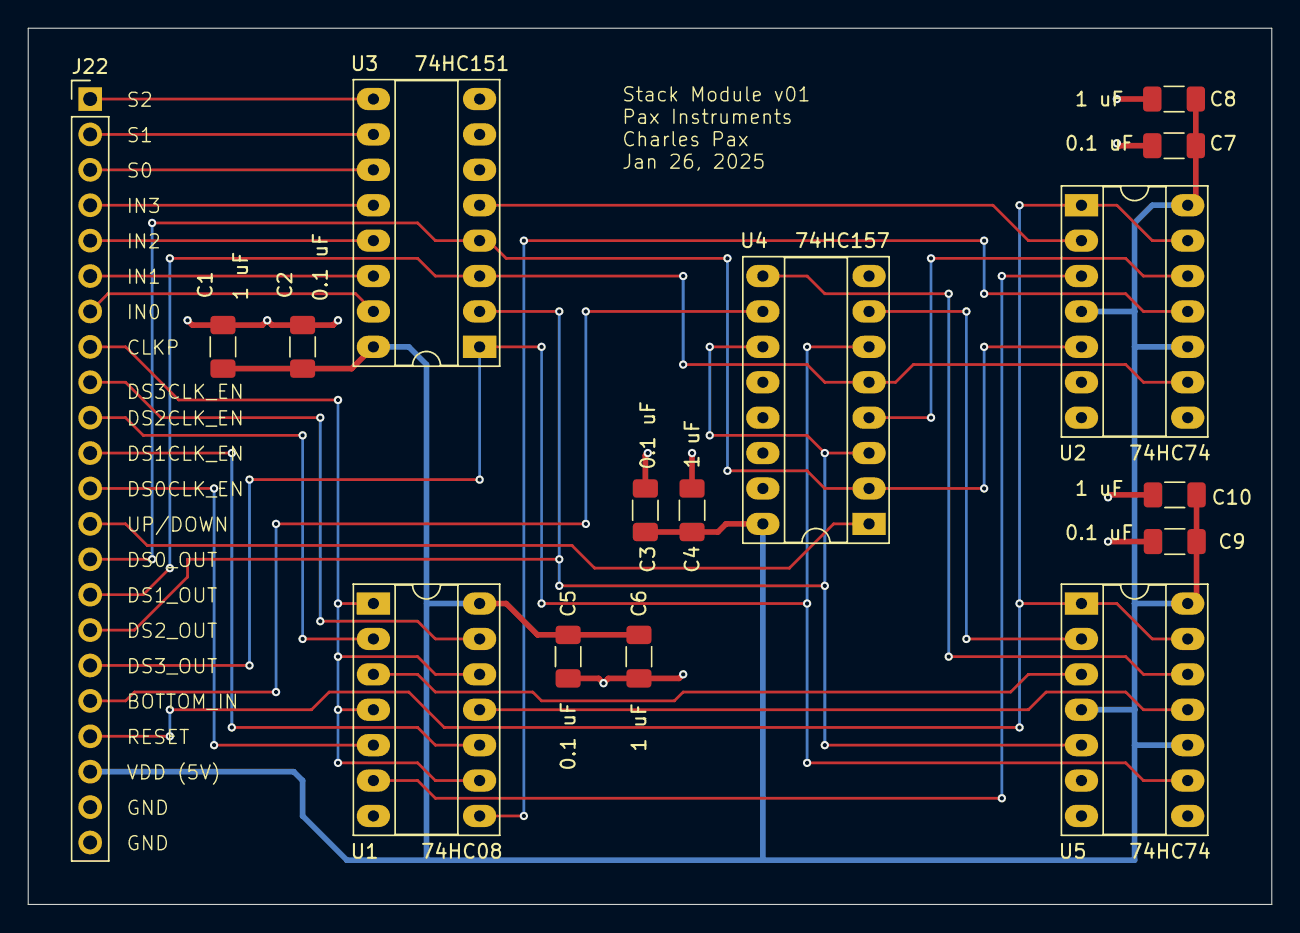
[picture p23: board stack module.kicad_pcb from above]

Board: 2 copper layers, 89.2 x 62.9 mm, 16 parts (0 on the bottom side), 29 nets.

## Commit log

2023-02-06 Added print.sh, which prints the text fifty lines at a time to the default printer.
2023-02-10 Added larger diagram. updated print script. Added 3d cube to scratchpad.
2023-02-10 Final format and print for the day. No notes for now.
2024-12-25 added a HDigital circuit for a bit lice ALU
2025-01-02 added a diode matrix rom to the simulation
2025-01-04 simulation steps through diode matrix rom
2025-01-27 added a stack module PCB design and some hmdigital circuits.
    [footprints.kicad_pcb, footprints.kicad_sch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]
2025-01-29 added a small stack module experiment.
    [stack module.kicad_sch, temp-kicad.kicad_pcb, temp-kicad.kicad_sch]
2025-02-04 added some kicad files.
    [diode matrix rom.kicad_pcb, diode matrix rom.kicad_sch, stack DIP.kicad_pcb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]
2025-02-14 Added diode-matrix-rom-dip
    [diode-matrix-rom-dip-B_Cu.gbl, diode-matrix-rom-dip-B_Mask.gbs, diode-matrix-rom-dip-B_Paste.gbp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]
2025-02-18 main board
    [mainboard-v01.kicad_pcb, mainboard-v01.kicad_sch]
